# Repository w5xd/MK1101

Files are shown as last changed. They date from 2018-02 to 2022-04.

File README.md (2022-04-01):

# MK1101 through MK1104
Morse generation and single-operator-on-2-Radios controller<br/>
Much more information and complete instructions are on the <a href='http://github.com/w5xd/MK1101/wiki'>Wiki</a>.

The most current design is the MK-1104 with its 3D printed enclosure. An older design, from 2017, is the MK-1101 and MK-1102 which
fit into aluminum enclosures manufactured by Bud. All the devices are functionally identical and nearly so with the much older MK-1100
that was manufactured by HAL.

The TextFixture and the Arduino sketch are shared among all the designs.

<h2>MK-1103 and MK-1104. 3D printed enclosures</h2>
MK1104-schematic.sch is an <a href='http://expresspcb.com'>expresspcb.com</a> schematic for both the MK1103 and MK1104.<br/>
MK1103-main.rrb is an <a href='http://expresspcb.com'>expresspcb.com</a> printed circuit layout for the main board used by both MK1103 and MK1104<br/>
MK1104-aux.rrb is an <a href='http://expresspcb.com'>expresspcb.com</a> printed circuit layout for the aux board used by the MK-1104.<br/>
TestFixture.rrb is an <a href='http://expresspcb.com'>expresspcb.com</a> printed circuit layout for a test fixture that eases check out and diagnostics.<br/>
MK110x.ino is the arduino firmware for all the variants.<br/>

<h2>MK-1101 and MK-1102. Aluminum enclosures from Bud</h2>

MK1102-schematic.sch is an <a href='http://expresspcb.com'>expresspcb.com</a> schematic for both the MK1101 and MK1102.<br/>
MK1101-main.rrb is an <a href='http://expresspcb.com'>expresspcb.com</a> printed circuit layout for the main board used by both MK1101 and MK1102<br/>
MK1102-aux.rrb is an <a href='http://expresspcb.com'>expresspcb.com</a> printed circuit layout for the aux board used by the MK-1102.<br/>
TestFixture.rrb is an <a href='http://expresspcb.com'>expresspcb.com</a> printed circuit layout for a test fixture that eases check out and diagnostics.<br/>
MK110x.ino is the arduino firmware.<br/>
MK1101-drilling-template.odg is an OpenOffice document with the drilling template drawing.<br/>
MK1101-lettering.odg is an OpenOffice document with the silkscreening.<br/>
pdfs of the OpenOffice templates are also in the pdf folder of this source archive.

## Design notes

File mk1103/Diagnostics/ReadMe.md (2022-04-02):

 This is a Win32 program that controls the AC0 and AC1 outputs on the FT232H chip made by ftdichip.com 
and used in
the MK-1103 and MK-1104. Those keyers have a solid state relay circuit that routes the TXD and RXD lines
from the FT232H normally to the RS232 level converter and the back panel Rig connector.
If AC0 is held low with AC1 high, the relay latches such that the arduino's TXD/RXD are on the COM port such that
its diagnostics can be run from through the FT232H. The Arduino can also have its program uploaded
with the latch in that state.

The FT232H has EEPROM settings that determine its power up state for AC0 and AC1 (among other settings.)
The EEPROM can be programmed using the FT-PROG program from ftdi: 
<a href='https://ftdichip.com/utilities/#ft_prog'>https://ftdichip.com/utilities/#ft_prog</a>
The MK-1103 and MK-1104 are specified to be programmed with EEPROM setting Drive_0 for AC1 and Drive_1 for
AC0, which routes the serial UART to the RS232 back panel Rig connector.

There are alternatives. Programming the EEPROM for AC1 high and AC0 low puts the FT232H and solid state
relay in diagnostic mode at power up (and therefore disables the Rig connector.)

The power up reset circuit on pin 1 of U20A holds the pin low long
enough to override the EEPROM settings. That means you may use ft_prog to program the FT232H EEPROM for
 AC0 to Drive_1 and AC1 to Tristate which sets
the EEPROM to leave the latch unchanged. That makes this program useful. Invoking this program for that EEPROM
setup sets or clears the latch:
  Diagnostics COMn on    sets the latch for diagnostics
  Diagnostics COMn off   sets the latch for RS232 on the Rig connector.

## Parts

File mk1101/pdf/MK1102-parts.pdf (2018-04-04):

## Cart Tools

### Input

New Cart - create a new empty cart
Fast Add - bulk add multiple part numbers to your cart
Add Carts - add previous carts
Add BOM - add existing BOMs
Add Quote - add previous Quotes Resume Cart - resume a previous cart Upload to Cart - upload a file, csv, txt, xls, xlsx

Upload to Cart

### Options

Schedule Shipments - schedule your order for a future release
Update Stock Status - refresh the quantity available

### Output

Download - save a copy of your cart in spreadsheet format
Cart Share - create a new cart including only the quantity, part number, and customer reference

Cart Share

Shopping Cart: MK1101-with aux

Web ID | 176618232 Access ID | 69159 Salesorder Number Uncommitted

Checkout Pricing is valid for this Web ID until 5/4/2018 if you place your order online.
Quantities are not reserved until the order has been submitted. | Continue Shopping
Quantity | Part Number | Customer Reference

All prices are in USD.

Index | Quantity | Image | Part Number | Description | Customer Reference | Available Quantity | Backorder Quantity | Unit Price | Extended Price
| | | | | CAP TANT 1UF 35V 10% RADIAL | | 5 Immediate | 0 | 1.09000 | $5.45
| | | | | CONN HEADER 32POS SOCKET 2.54MM | | 4 Immediate | 0 | 1.63000 | $6.52
| | | | | CONN HEADER 40 POS 2.54 | | 4 Immediate | 0 | 1.44000 | $5.76
| | | | | CAP CER 0.047UF 50V X7R RADIAL | | 12 Immediate | 0 | 0.15900 | $1.91
| | | | | FT232H USB TO GPIO/SPI/I2C | | 1 Immediate | 0 | 14.95000 | $14.95
| | | | | CAP CER 1000PF 50V X7R RADIAL | | 12 Immediate | 0 | 0.13300 | $1.60
| | | | | AUDIO MAGNETIC INDICATOR 4-7V TH | | 1 Immediate | 0 | 1.51000 | $1.51
| | | | | IC DUAL RS232 ESD-PROT 16-DIP | | 1 Immediate | 0 | 1.61000 | $1.61
| | | | | TRANS NPN 40V 0.2A TO-92 | | 3 Immediate | 0 | 0.21000 | $0.63
| | | | | POT 100K OHM 1/20W PLASTIC LIN | | 1 Immediate | 0 | 1.29000 | $1.29
| | | | | CONN HEADER .100" DUAL STR 40POS | | 3 Immediate | 0 | 0.93000 | $2.79
| | | | | ATMEGA328 ARDUINO PRO MINI 5V | | 1 Immediate | 0 | 9.95000 | $9.95
| | | | | OPTOISO 5KV 4CH DARLINGTON 16DIP | | 1 Immediate | 0 | 3.47000 | $3.47
| | | | | CONN D-SUB RCPT 25POS STR IDC | | 2 Immediate | 0 | 2.33000 | $4.66
1 | 399-1429-ND
2 | 732-2860-ND
3 | 732-5334-ND
4 | BC1082CT-ND
5 | 1528-1449-ND
6 | BC1072CT-ND
7 | 668-1458-ND
8 | 296-26139-5-ND
9 | 2N3904FS-ND
10 | 987-1708-ND
11 | S2011EC-20-ND
12 | 1568-1055-ND
13 | PS2502-4A-ND
14 | HFM25H-ND
Online Ordering | Digi-Key | https://www.digikey.com/classic/Ordering/AddPart.aspx

15 | 450-2102-ND
| SWITCH TOGGLE SPDT 3A 120V | 1 Immediate | 0 | 2.99000 | $2.99
| CBL RIBN 25COND 0.050 GRAY 10' | 1 Immediate | 0 | 9.98000 | $9.98
| CONN HEADER 40 POS RA 2.54 | 1 Immediate | 0 | 1.44000 | $1.44
| CBL RIBN 8COND 0.050 GRAY 10' | 1 Immediate | 0 | 11.25000 | $11.25
| IC LINE RCVR RS485 QUAD 16-DIP | 1 Immediate | 0 | 6.66000 | $6.66
| BOX ALUM BLACK 2.72"L X 4.53"W | 1 Immediate | 0 | 24.90000 | $24.90
| CONN SOCKET IDC 8POS DL SR 30AU | 2 Immediate | 0 | 0.99000 | $1.98
| IC DVR RS485 LOW PWR QUAD 16-DIP | 1 Immediate | 0 | 7.28000 | $7.28
| CONN PWR JACK 2X5.5MM KINKED PIN | 1 Immediate | 0 | 0.60000 | $0.60
| IC 8-BIT SHIFT REGISTER 16-DIP | 2 Immediate | 0 | 0.53000 | $1.06
| CONN SOCKET IDC 26POS DUAL 30AU | 2 Immediate | 0 | 2.03000 | $4.06
| CONN SOCKET IDC 10POS DUAL 30AU | 1 Immediate | 0 | 1.19000 | $1.19
| CBL RIBN 10COND 0.050 GRAY 5' | 1 Immediate | 0 | 3.36000 | $3.36
| CONN D-SUB PLUG 9POS STR IDC | 1 Immediate | 0 | 1.82000 | $1.82
| RES 180 OHM 1/8W 5% CF AXIAL | 3 Immediate | 0 | 0.10000 | $0.30
| IC REG LINEAR 5V 1A TO220-3 | 1 Immediate | 0 | 0.90000 | $0.90
TPMSCT-ND | DIODE GEN PURP 75V 150MA DO35 | 2 Immediate | 0 | 0.11000 | $0.22
| RELAY GENERAL PURPOSE SPDT 1A 5V | 0 Immediate | 2 Lead Time | 1.99000 | $3.98
16 | AE25G-10-ND
17 | 732-5350-ND
18 | MD08R-10-ND
19 | LTC488CN#PBF- ND
20 | 377-2511-ND
21 | 609-3568-ND
22 | LTC486CN#PBF- ND
23 | CP-202A-ND
24 | 296-1600-5-ND
25 | 609-1742-ND
26 | 609-1739-ND
27 | AE10G-5-ND
28 | HMM09H-ND
29 | CF18JT180RCT- ND
30 | LM7805ACT-ND
31 | 1N4148-
32 | Z773-ND
33 | 497-5231-1-ND

DIODE GEN
PURP 600V
5A DO201AD

1
Immediate | 0 | 0.97000 | $0.97

Copyright © 1995-2018, Digi-Key Electronics. All Rights Reserved.
701 Brooks Avenue South,
Thief River Falls, MN 56701 USA
Continue Shopping | Checkout
Questions? Give us a call at 1-800-344-4539 or chat with us now on | .
34 | 1568-1103-ND
IC BRIDGE USB-UART 5V MODULE | 1 Immediate | 0 | 14.95000 | $14.95
CONN PWR PLUG 2.1X5.5MM SOLDER | 1 Immediate | 0 | 1.04000 | $1.04
RES 10K OHM 1/8W 5% CF AXIAL | 1 Immediate | 0 | 0.10000 | $0.10
RES 1K OHM 1/8W 5% CF AXIAL | 7 Immediate | 0 | 0.10000 | $0.70
CONN JACK STEREO 3.5MM R/A | 0 Immediate | 9 Lead Time | 2.30000 | $20.70
35 | CP3-1000-ND
36 | CF18JT10K0CT- ND
37 | CF18JT1K00CT- ND
38 | CP-3504-ND
Subtotal | $184.53
Shipping | Estimate
Sales Tax | unknown
Total | unknown

Are you shipping outside the United States?

Information: Please refer to our Terms and Conditions and Privacy Statement.

Live Chat

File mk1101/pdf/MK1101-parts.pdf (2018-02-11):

## Cart Tools

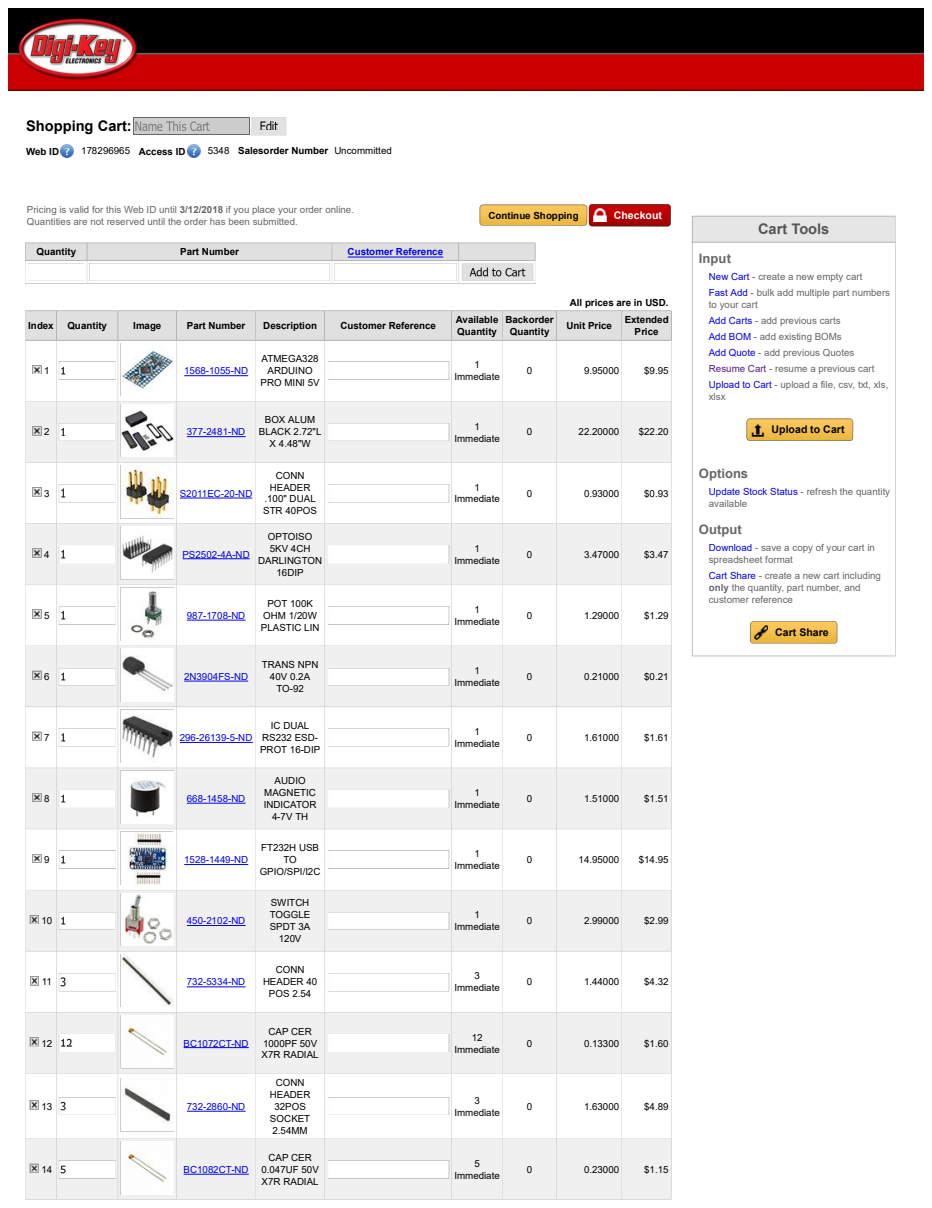
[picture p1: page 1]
Upload to Cart - upload a file, csv, txt, xls, xlsx; Upload to Cart; Shopping Cart: Web ID; 178296965 Access ID; 5348 Salesorder Number Uncommitted; Checkout Pricing is valid for this Web ID until 3/12/2018 if you place your order online.; Quantities are not reserved until the order has been submitted.; Continue Shopping; Quantity; Part Number; Customer Reference; All prices are in USD.

Input New Cart - create a new empty cart Fast Add - bulk add multiple part numbers

to your cart Add Carts - add previous carts Add BOM - add existing BOMs

Index | Quantity | Image | Part Number | Description | Customer Reference | Available Quantity | Backorder Quantity | Unit Price | Extended Price

Add Quote - add previous Quotes Resume Cart - resume a previous cart

ATMEGA328 ARDUINO PRO MINI 5V | | 1 Immediate | 0 | 9.95000 | $9.95

BOX ALUM BLACK 2.72"L X 4.48"W | | 1 Immediate | 0 | 22.20000 | $22.20

Options
Update Stock Status - refresh the quantity available Output Download - save a copy of your cart in

CONN HEADER .100" DUAL STR 40POS | | 1 Immediate | 0 | 0.93000 | $0.93

4 | | | PS2502-4A-ND | OPTOISO 5KV 4CH DARLINGTON 16DIP | | 1 Immediate | 0 | 3.47000 | $3.47

spreadsheet format Cart Share - create a new cart including

only the quantity, part number, and
customer reference Cart Share

POT 100K OHM 1/20W PLASTIC LIN | | 1 Immediate | 0 | 1.29000 | $1.29

TRANS NPN 40V 0.2A TO-92 | | 1 Immediate | 0 | 0.21000 | $0.21

IC DUAL RS232 ESD- PROT 16-DIP | | 1 Immediate | 0 | 1.61000 | $1.61

AUDIO MAGNETIC INDICATOR 4-7V TH | | 1 Immediate | 0 | 1.51000 | $1.51

FT232H USB TO GPIO/SPI/I2C | | 1 Immediate | 0 | 14.95000 | $14.95

SWITCH TOGGLE SPDT 3A 120V | | 1 Immediate | 0 | 2.99000 | $2.99

CONN HEADER 40 POS 2.54 | | 3 Immediate | 0 | 1.44000 | $4.32

CAP CER 1000PF 50V X7R RADIAL | | 12 Immediate | 0 | 0.13300 | $1.60

CONN HEADER 32POS SOCKET 2.54MM | | 3 Immediate | 0 | 1.63000 | $4.89

CAP CER 0.047UF 50V X7R RADIAL | | 5 Immediate | 0 | 0.23000 | $1.15

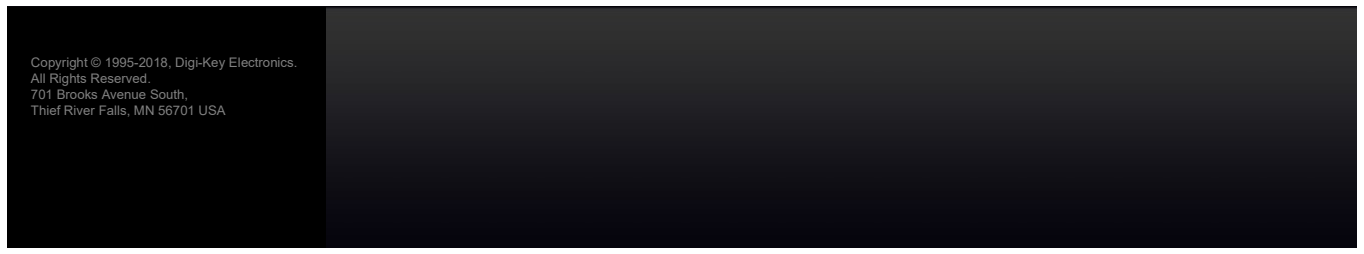
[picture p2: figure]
All Rights Reserved. 701 Brooks Avenue South, Thief River Falls, MN 56701 USA

Copyright © 1995-2018, Digi-Key Electronics.

Continue Shopping | Checkout
Questions? Give us a call at 1-800-344-4539 or chat with us now on | .

15 399-1429-ND

CAP TANT 1UF 35V 10% RADIAL | 4 Immediate | 0 | 1.09000 | $4.36
CONN JACK STEREO 3.5MM R/A | 0 Immediate | 6 Lead Time | 2.30000 | $13.80
CONN D-SUB PLUG 9POS STR IDC | 1 Immediate | 0 | 1.84000 | $1.84
CBL RIBN 10COND 5' 0.050 GRAY | 1 Immediate | 0 | 3.36000 | $3.36
IC BRIDGE USB-UART 5V MODULE | 1 Immediate | 0 | 14.95000 | $14.95
CONN SOCKET IDC 10POS DUAL 30AU | 1 Immediate | 0 | 1.19000 | $1.19
CONN HEADER 40 POS RA 2.54 | 1 Immediate | 0 | 1.44000 | $1.44
RES 10K OHM 1/8W 5% CF AXIAL | 1 Immediate | 0 | 0.10000 | $0.10
RES 1K OHM 1/8W 5% CF AXIAL | 5 Immediate | 0 | 0.10000 | $0.50

### 16 CP-3504-ND

### 17 HMM09H-ND

### 18 AE10G-5-ND

19 1568-1103-ND

20 609-1739-ND

21 732-5350-ND

### 22 CF18JT10K0CT- ND

### 23 CF18JT1K00CT- ND

Subtotal | | $112.61
Shipping | Estimate Sales Tax | unknown
Total | unknown Are you shipping outside the United States?

Information: Please refer to our Terms and Conditions and Privacy Statement. Live Chat

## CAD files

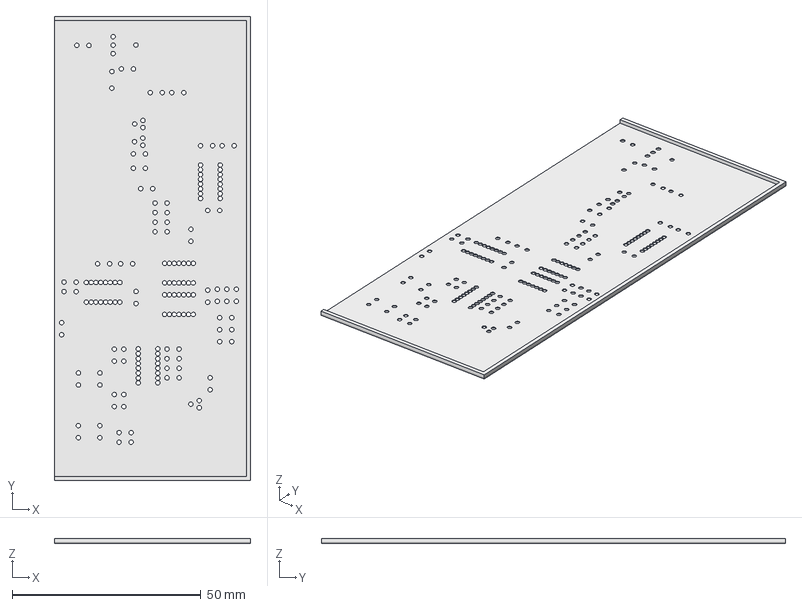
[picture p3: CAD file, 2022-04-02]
mk1103/pcb step/mk1103-main-solder-paste.step
52.0 x 123.0 x 1.20 mm

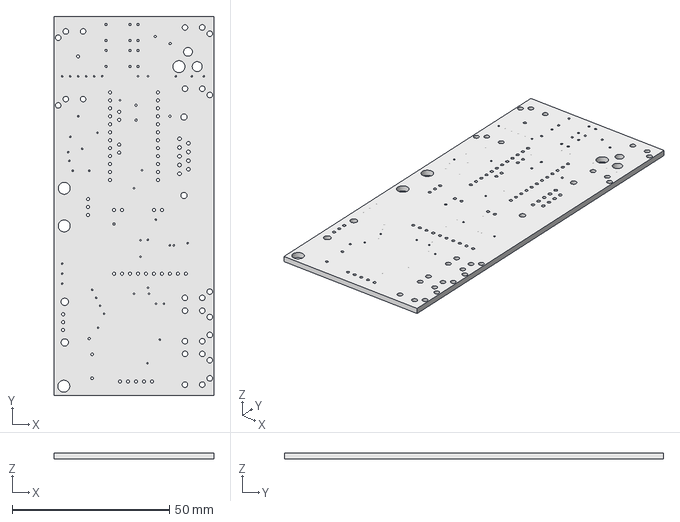
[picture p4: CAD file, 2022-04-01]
mk1103/pcb step/pcb-main.step
50.8 x 120.7 x 1.78 mm

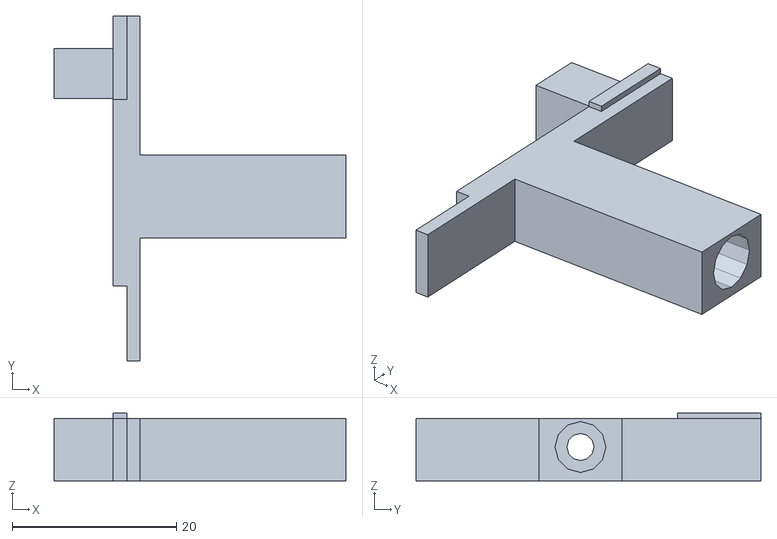
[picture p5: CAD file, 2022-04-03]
mk1103/STL/pcb-main-brace.stl
35.6 x 42.1 x 8.26

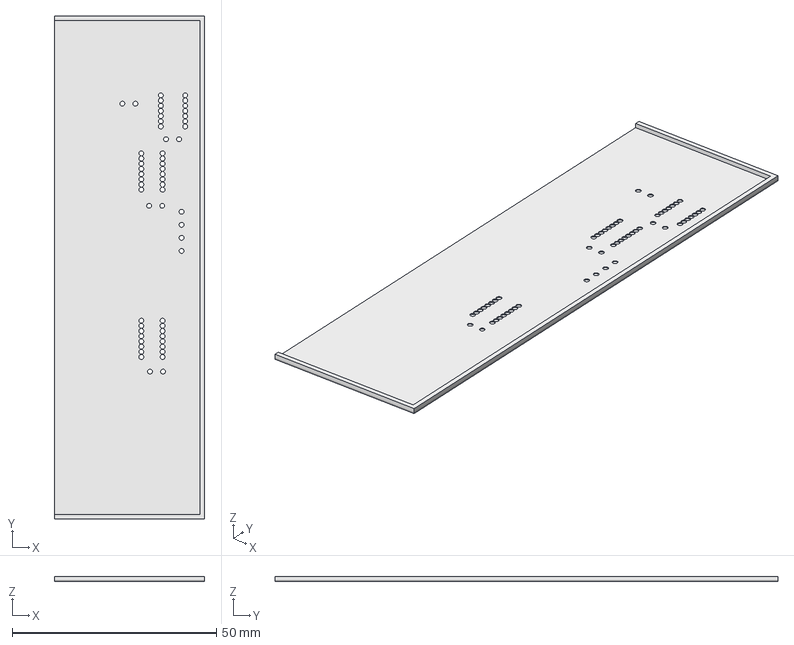
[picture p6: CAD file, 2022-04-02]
mk1103/pcb step/mk1104-solder-paste.step
36.8 x 123.0 x 1.20 mm

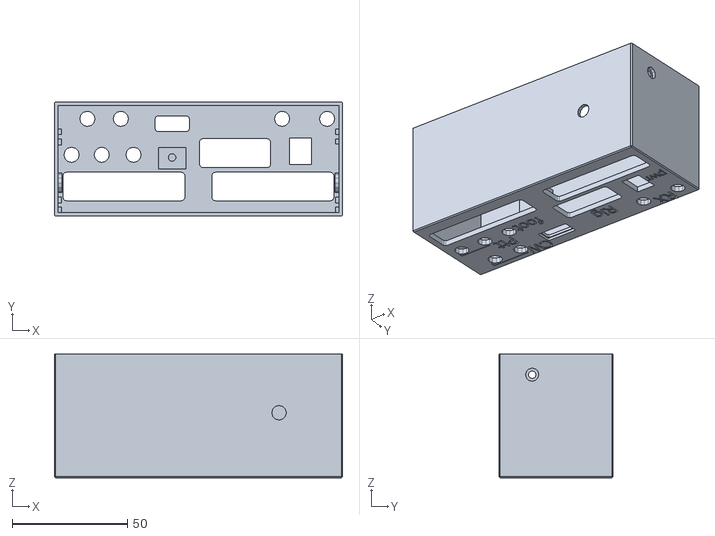
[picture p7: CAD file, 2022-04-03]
mk1103/STL/enclosure-1104-back.stl
124.8 x 49.6 x 53.6

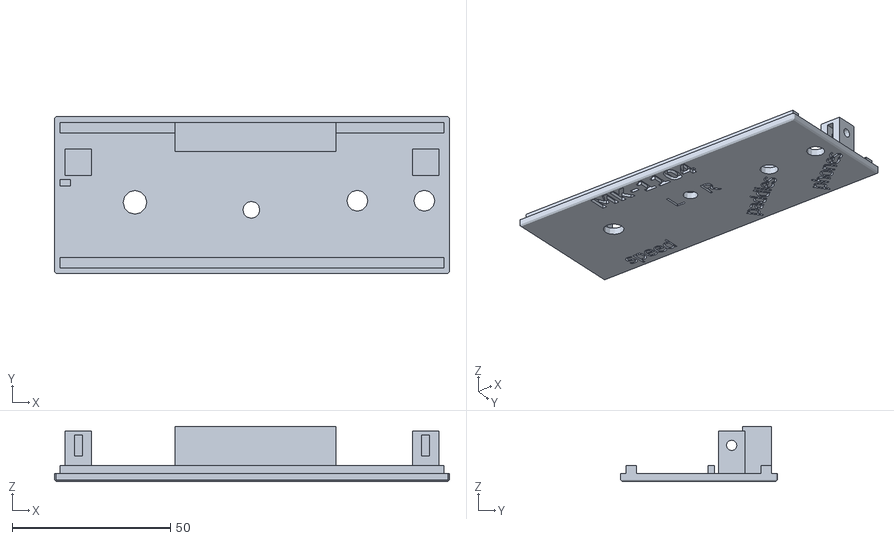
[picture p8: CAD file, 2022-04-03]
mk1103/STL/enclosure-1104-front.stl
124.8 x 49.6 x 17.4

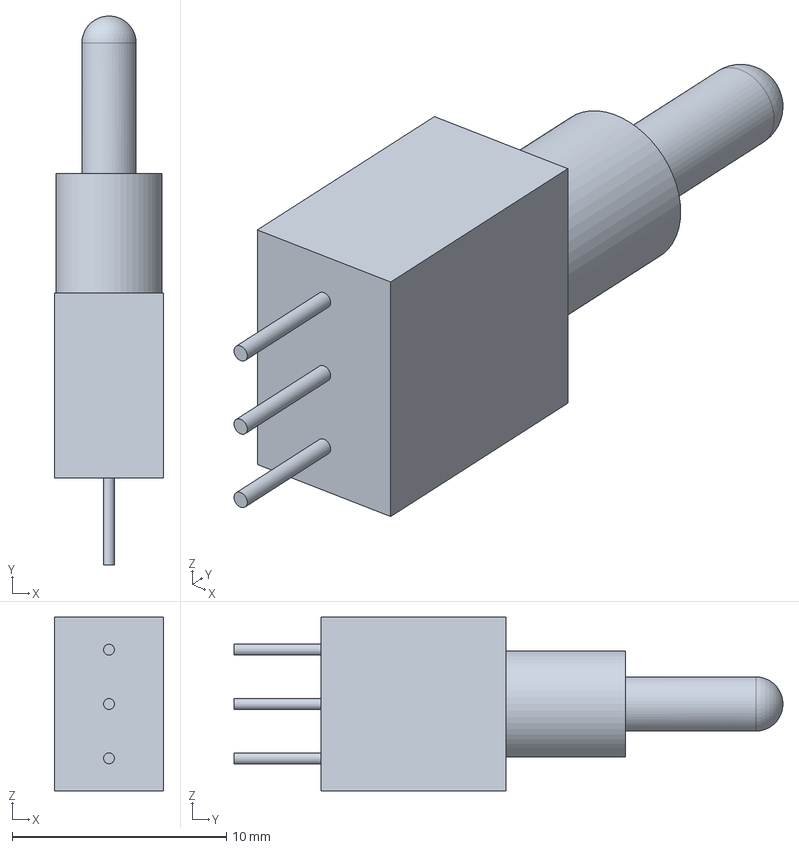
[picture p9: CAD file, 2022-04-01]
mk1103/pcb step/LR switch.stp
5.08 x 25.7 x 8.13 mm

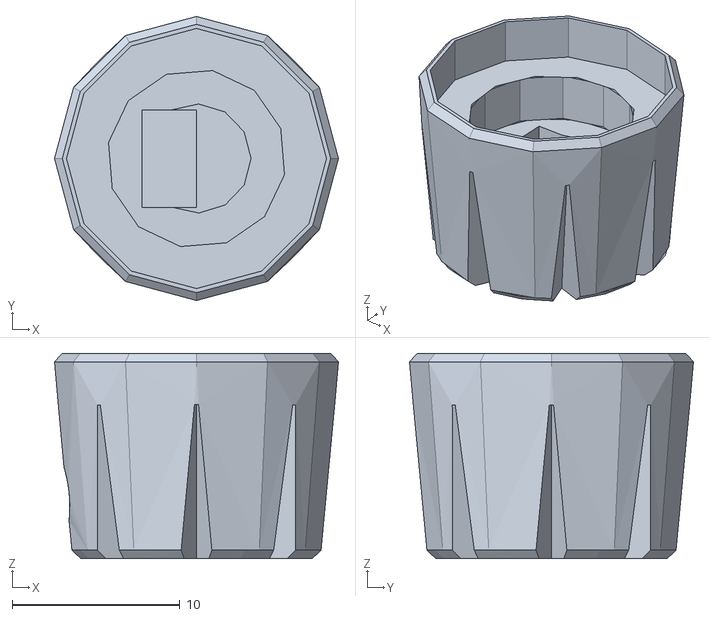
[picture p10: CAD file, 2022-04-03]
mk1103/STL/speed knob.stl
16.9 x 16.9 x 12.2

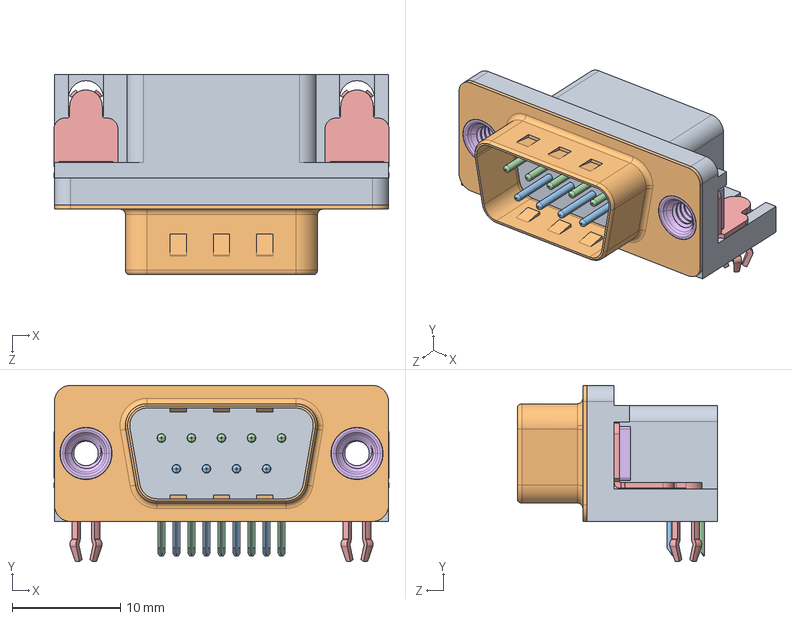
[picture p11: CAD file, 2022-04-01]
mk1103/pcb step/621-009-260-042 - EDAC D-Sub Connector.STEP
30.9 x 16.3 x 18.4 mm
621 Housing_9 Socket
621 Shell_9 Socket
621 Contact Bottom x 4
621 Contact Top x 5
621 4 Prong Board Lock x 2
621 4-40 Threaded Rivet x 2

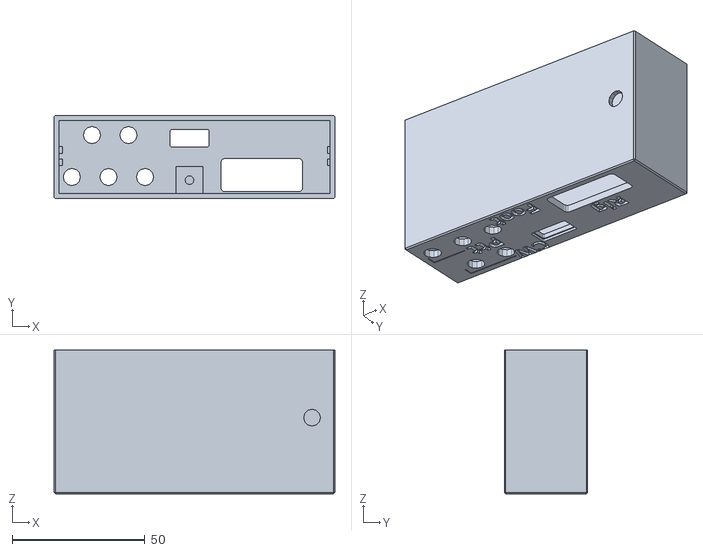
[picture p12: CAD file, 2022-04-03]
mk1103/STL/enclosure-1103-back.stl
105.9 x 31.4 x 54.1

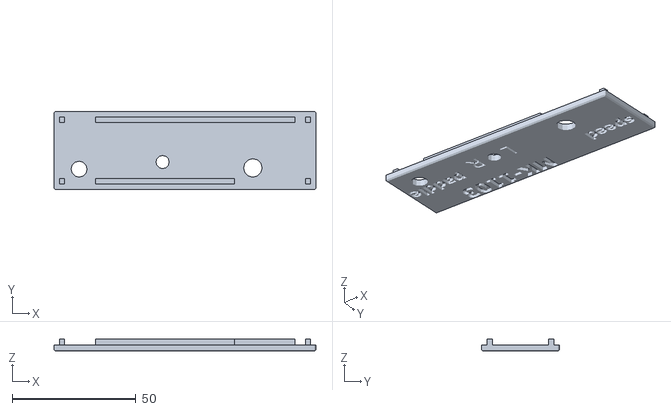
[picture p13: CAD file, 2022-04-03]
mk1103/STL/enclosure-1103-front.stl
105.9 x 31.4 x 5.01

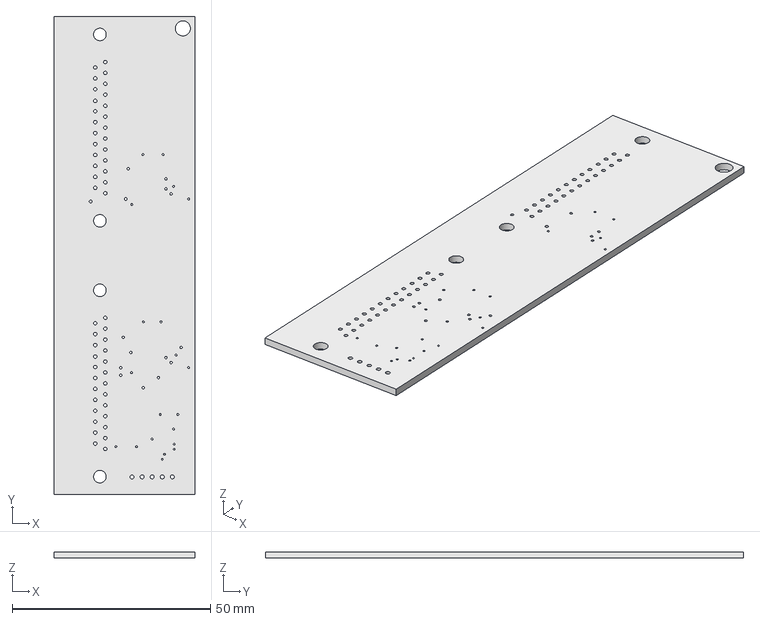
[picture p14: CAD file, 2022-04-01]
mk1103/pcb step/pcb-aux.step
35.6 x 120.7 x 1.59 mm

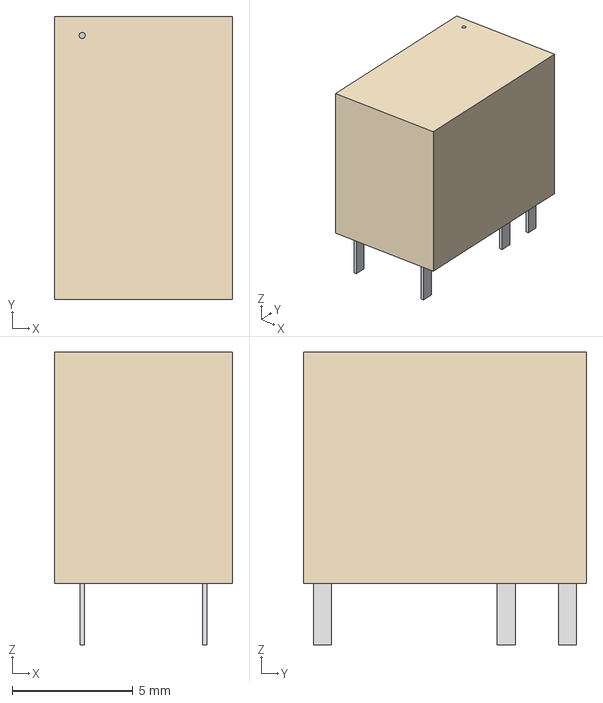
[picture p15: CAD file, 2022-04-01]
mk1103/pcb step/RELAY_HY1_PAN.step
7.39 x 11.7 x 12.1 mm

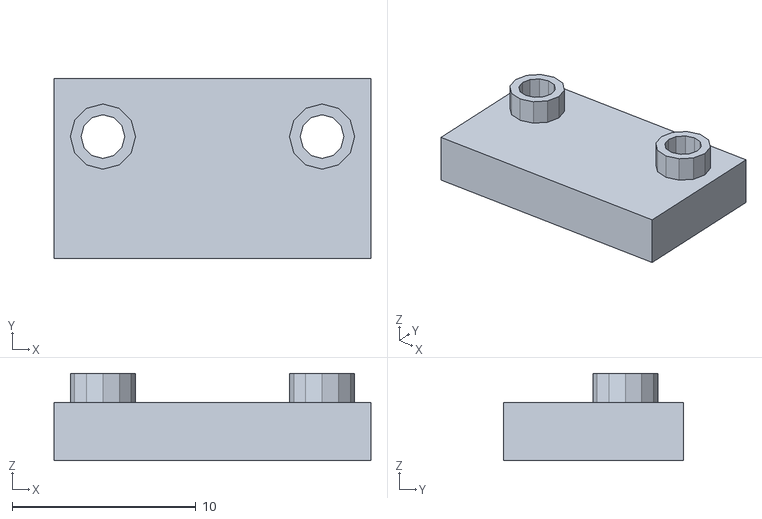
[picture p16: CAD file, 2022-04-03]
mk1103/STL/switch spacer.stl
17.3 x 9.83 x 4.76

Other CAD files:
mk1103/pcb step/Relay SPDT.stp
mk1103/pcb step/PDB25S564GTLF.stp
mk1103/pcb step/switch spacer.stp
mk1103/pcb step/speed pot.stp
mk1103/pcb step/buzzer.stp

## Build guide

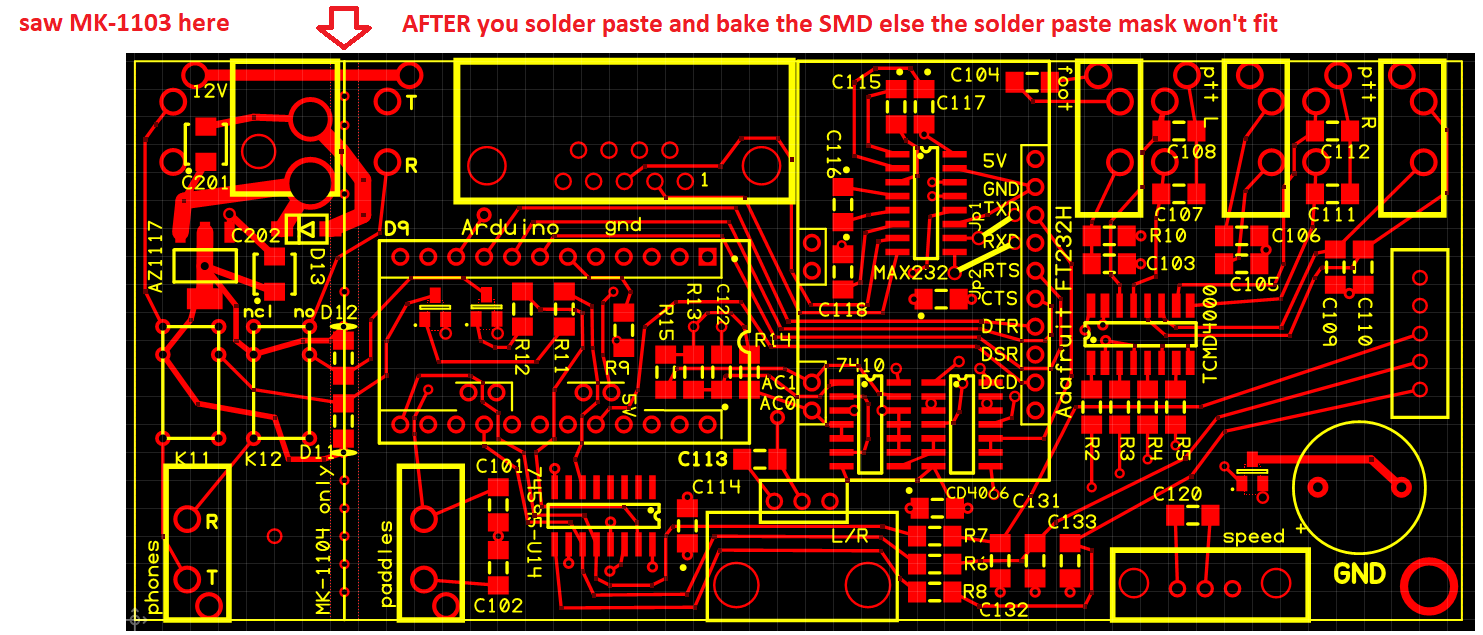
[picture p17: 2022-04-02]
mk1103/mk1103-board-cutting-instructions.png

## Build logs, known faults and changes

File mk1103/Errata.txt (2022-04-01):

Errata

1. The solder mask for the main board does NOT fit after the PCB is cut for the MK-1103 configuration. Therefore: do NOT cut the PCB
until AFTER the surface mount components are baked on.

2. The only bottom-side components (besides the D13 issue above) are: 
    FT232H breakout
    Ptt out connectors
    RX audio in connectors (and these are only present in the MK-1104 configuration)

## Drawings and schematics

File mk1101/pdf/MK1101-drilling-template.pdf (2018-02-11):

# Back

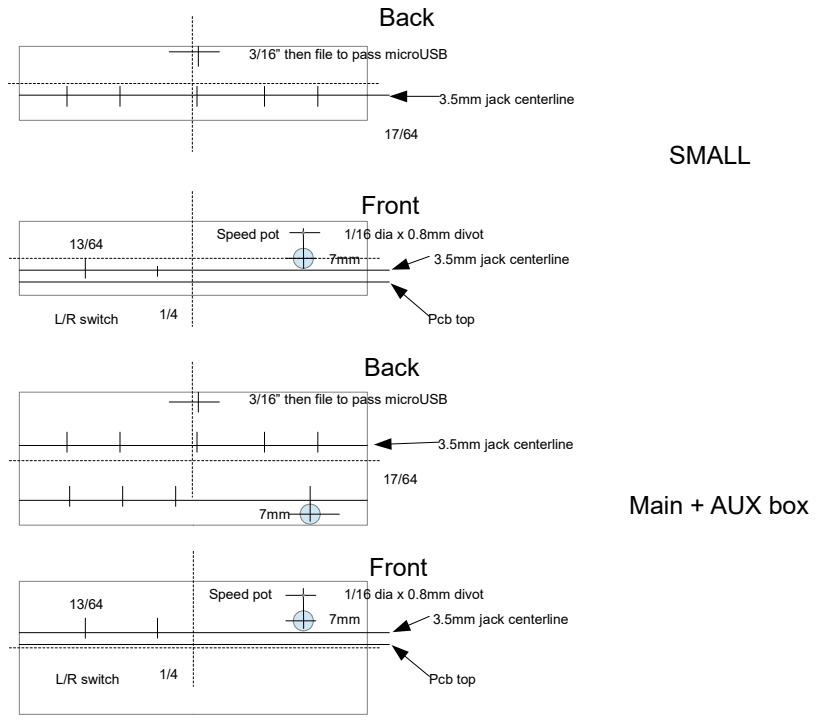
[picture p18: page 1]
3.5mm jack centerline; Pcb top; Front; Speed pot; L/R switch; 1/16 dia x 0.8mm divot 13/64; Back; SMALL; Main + AUX box

3/16” then file to pass microUSB

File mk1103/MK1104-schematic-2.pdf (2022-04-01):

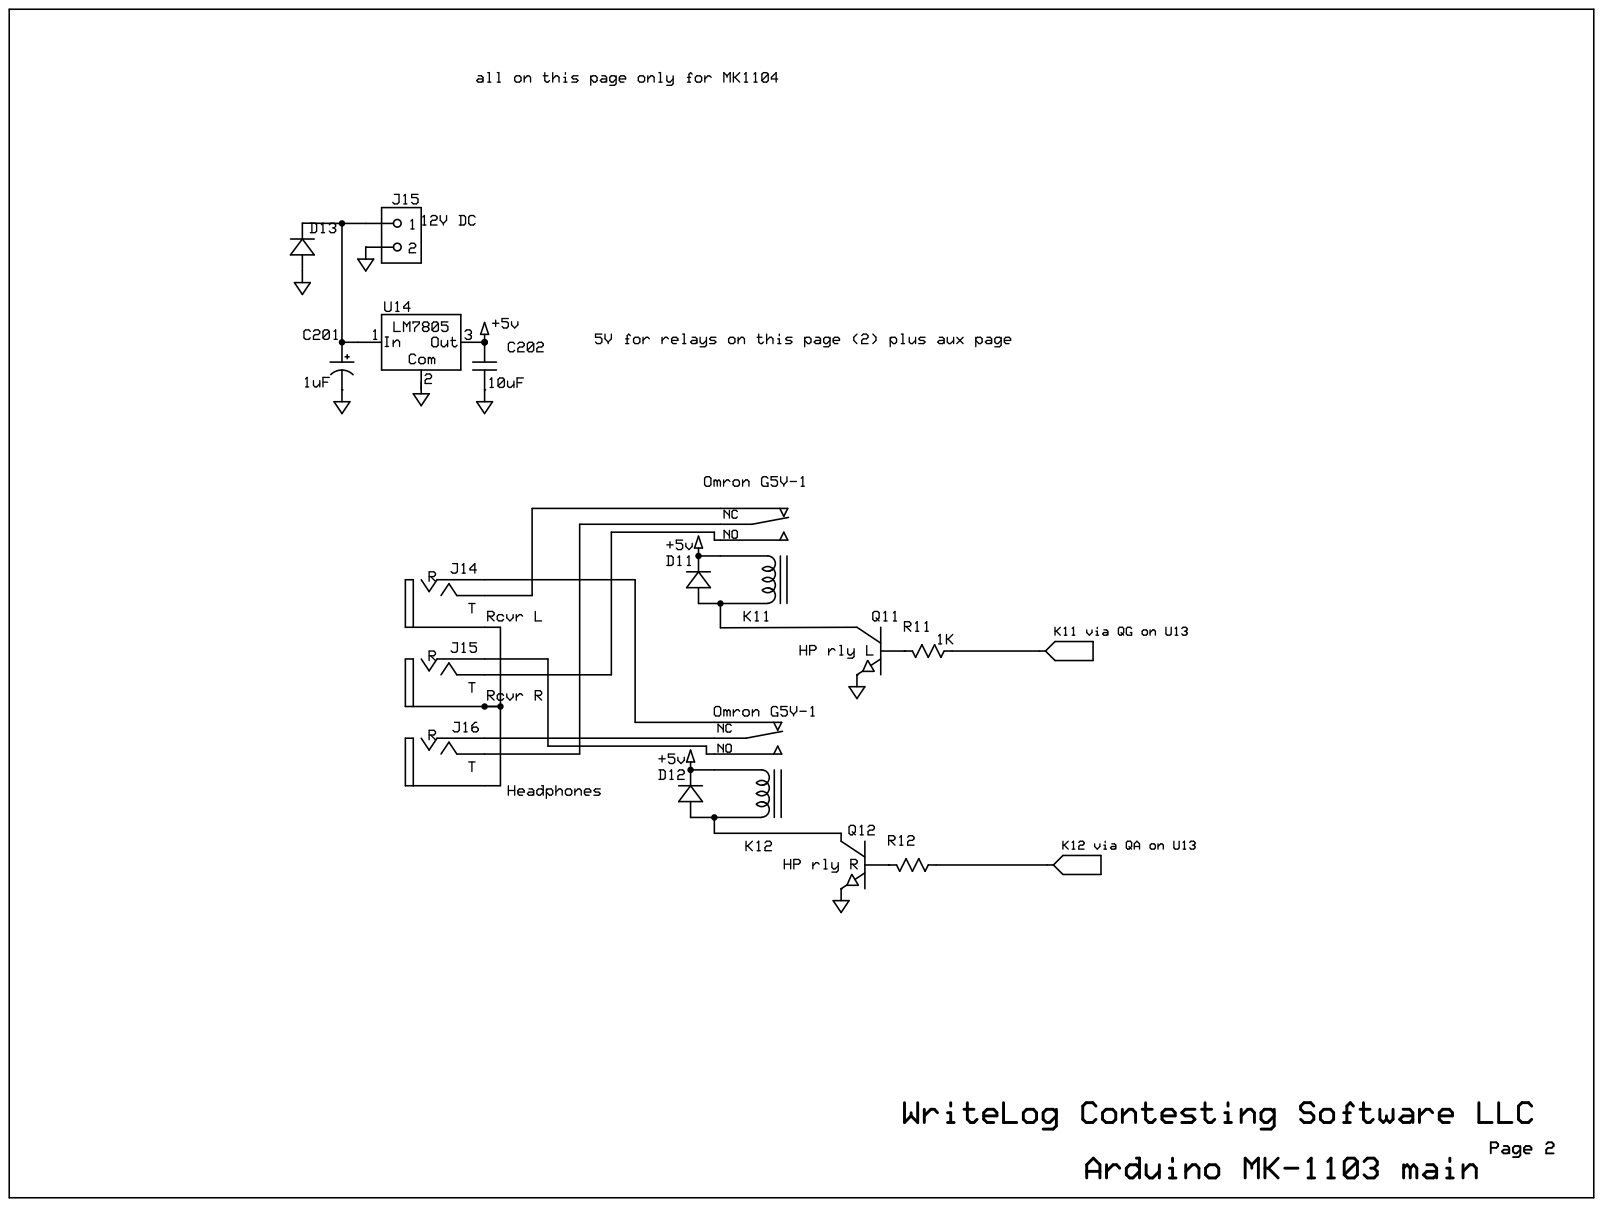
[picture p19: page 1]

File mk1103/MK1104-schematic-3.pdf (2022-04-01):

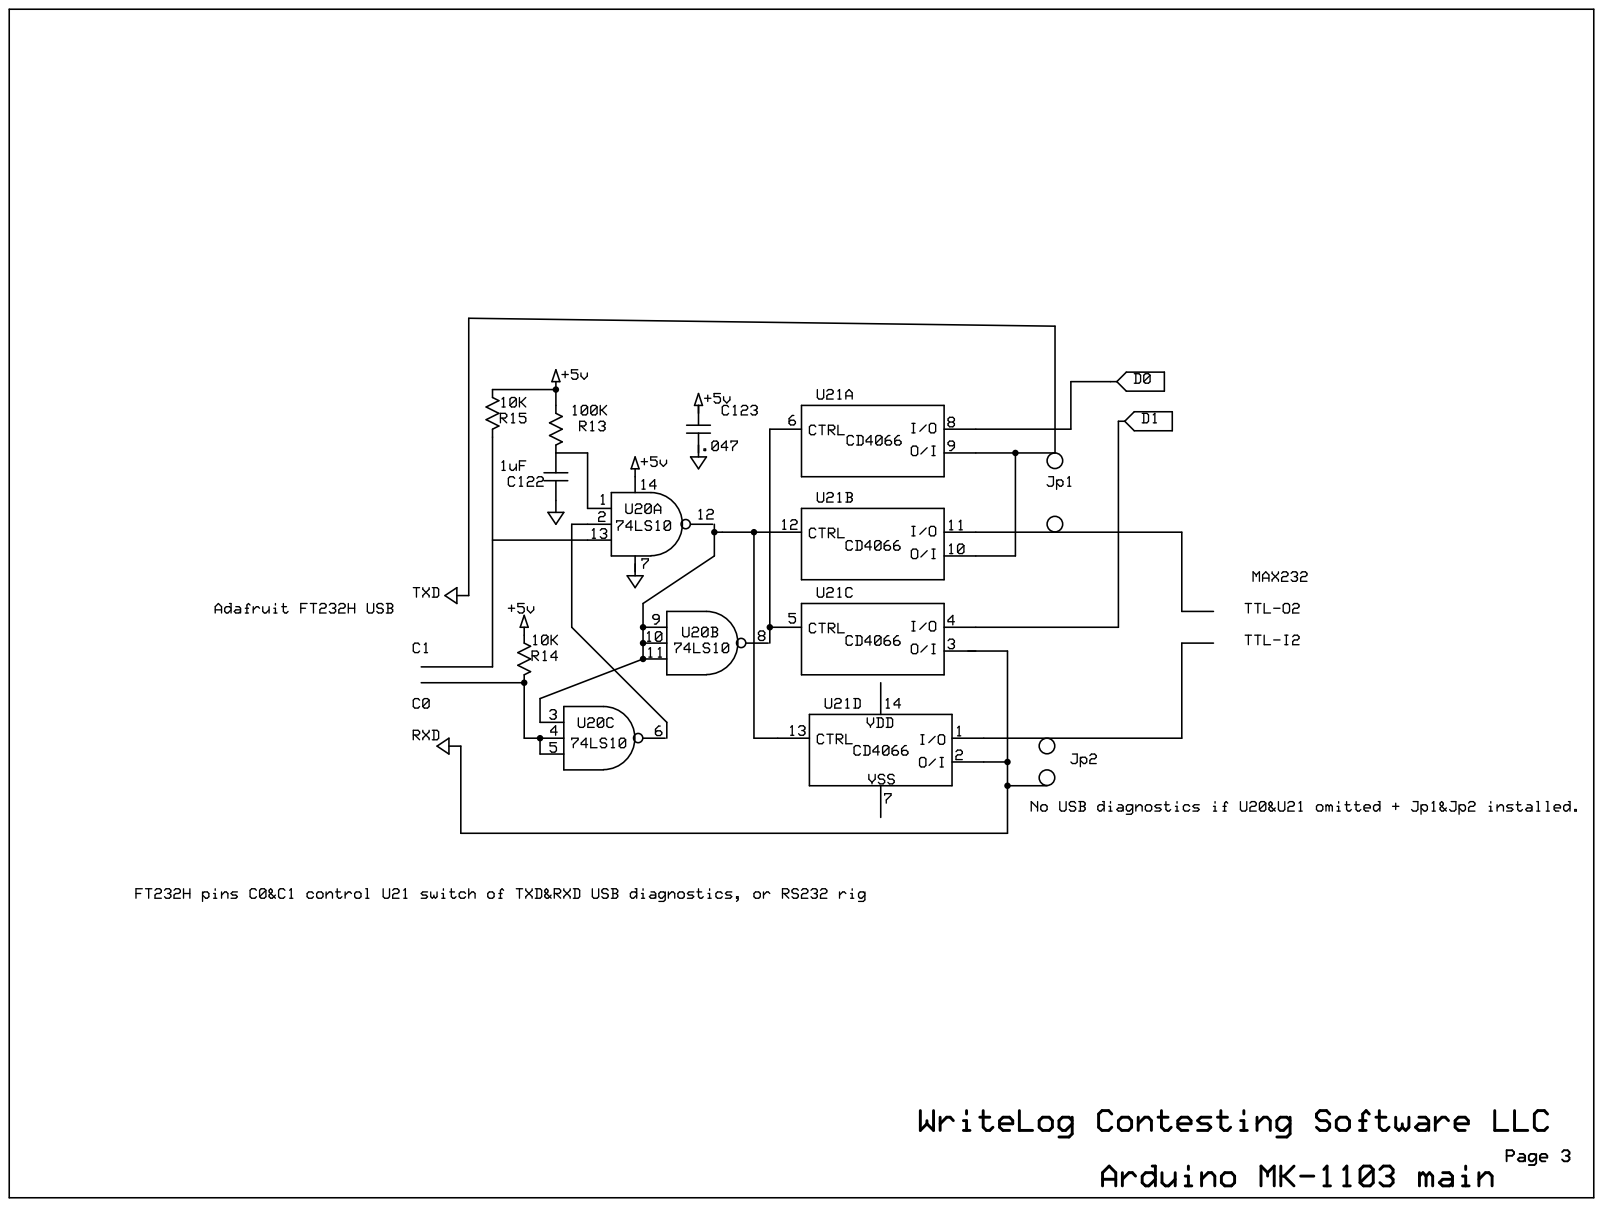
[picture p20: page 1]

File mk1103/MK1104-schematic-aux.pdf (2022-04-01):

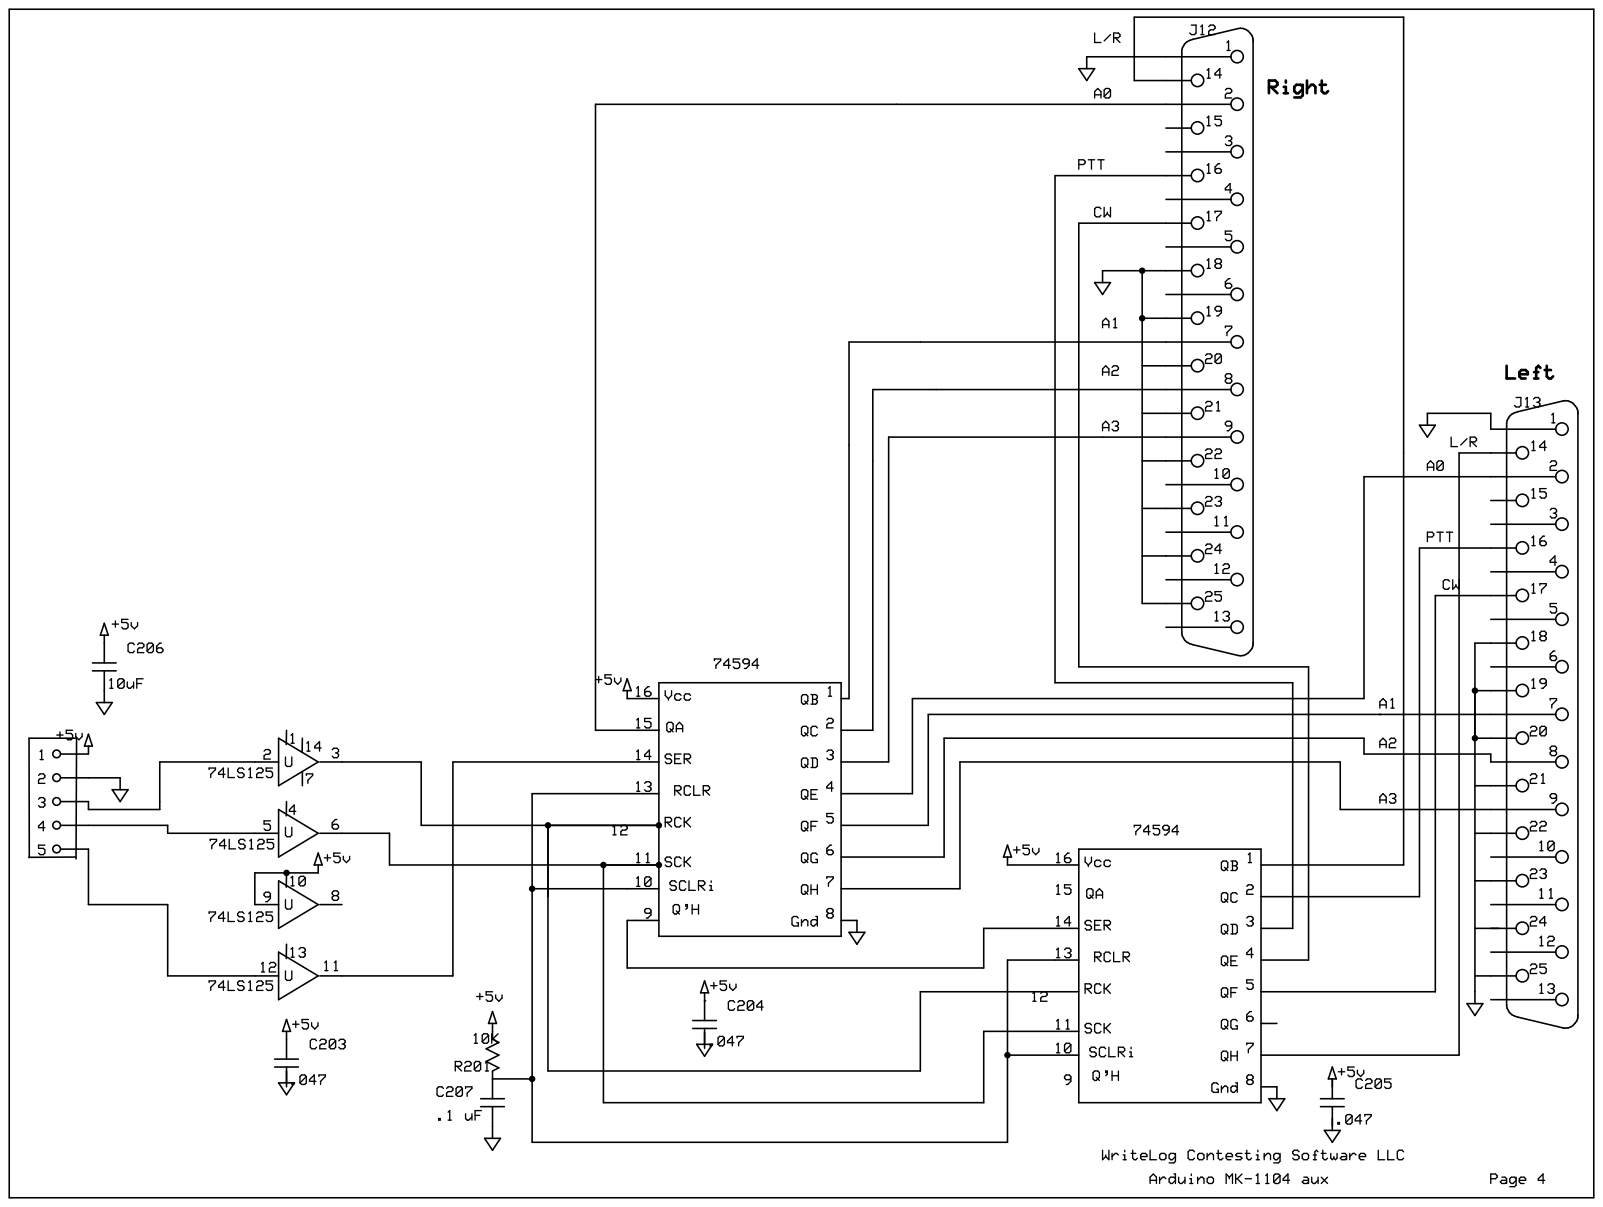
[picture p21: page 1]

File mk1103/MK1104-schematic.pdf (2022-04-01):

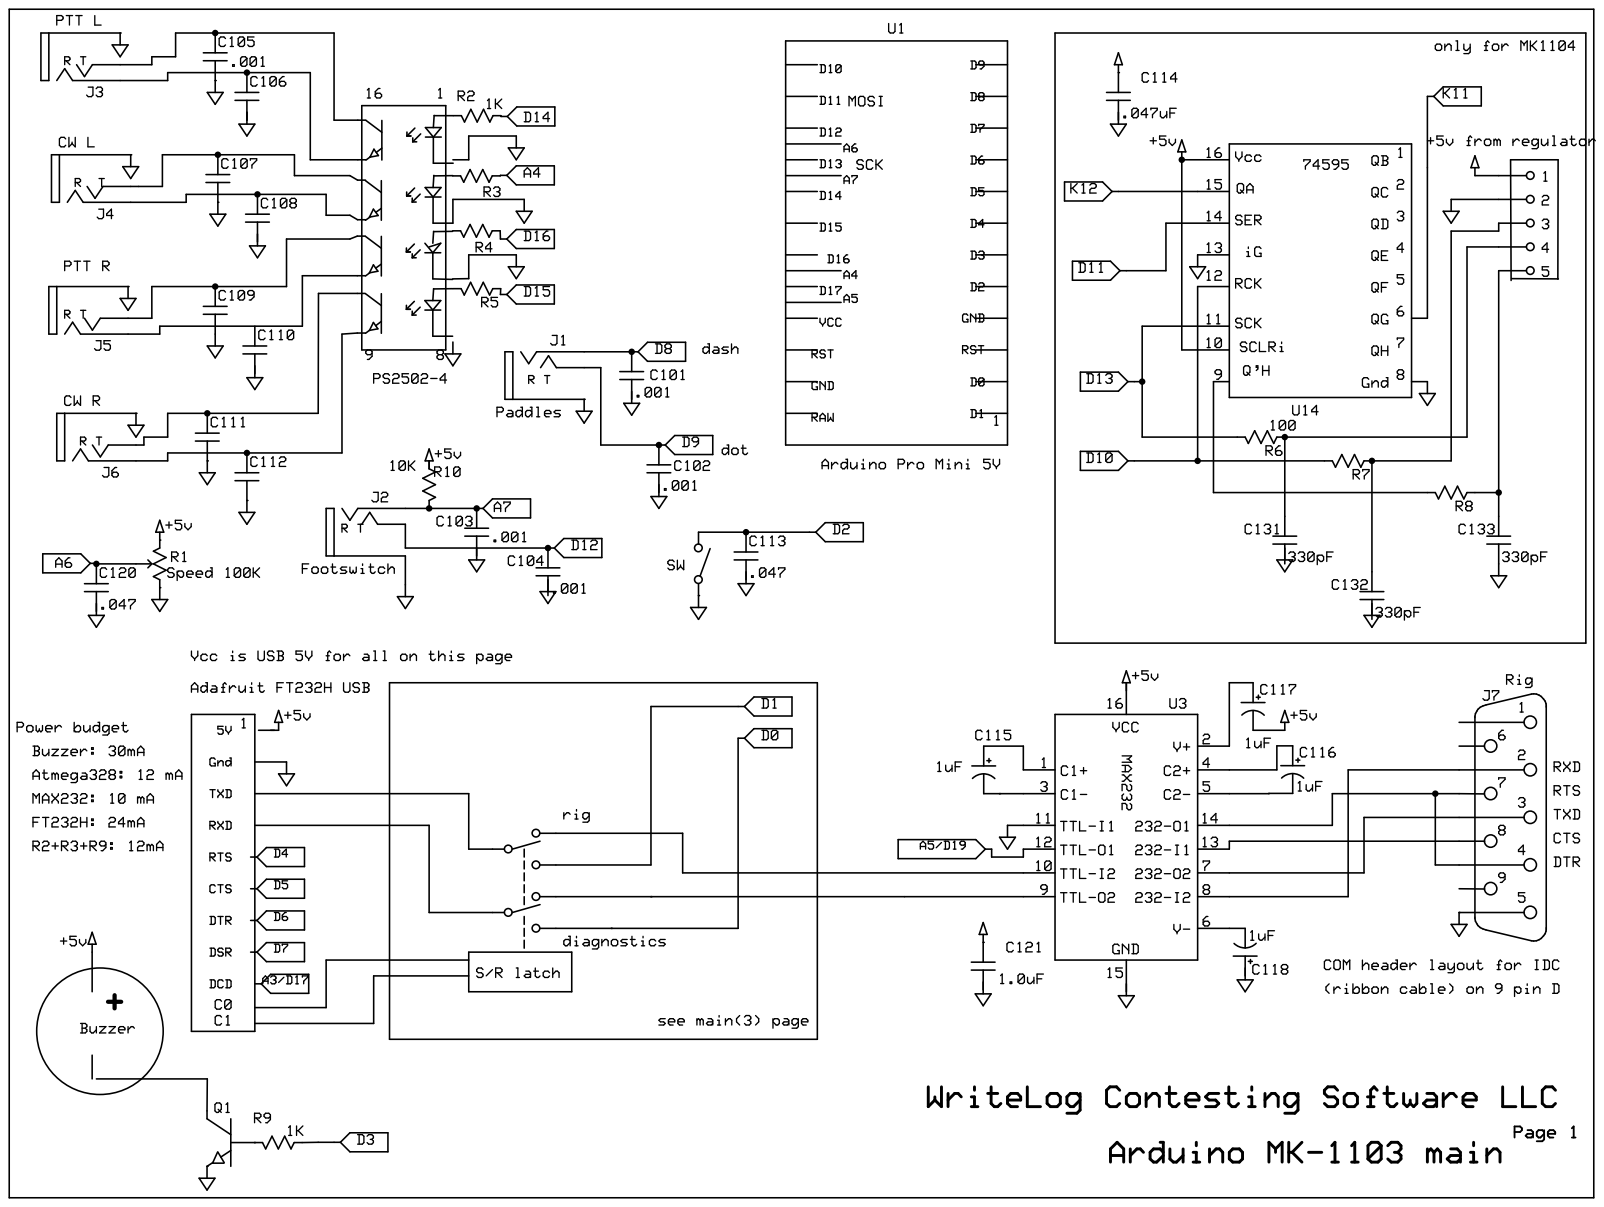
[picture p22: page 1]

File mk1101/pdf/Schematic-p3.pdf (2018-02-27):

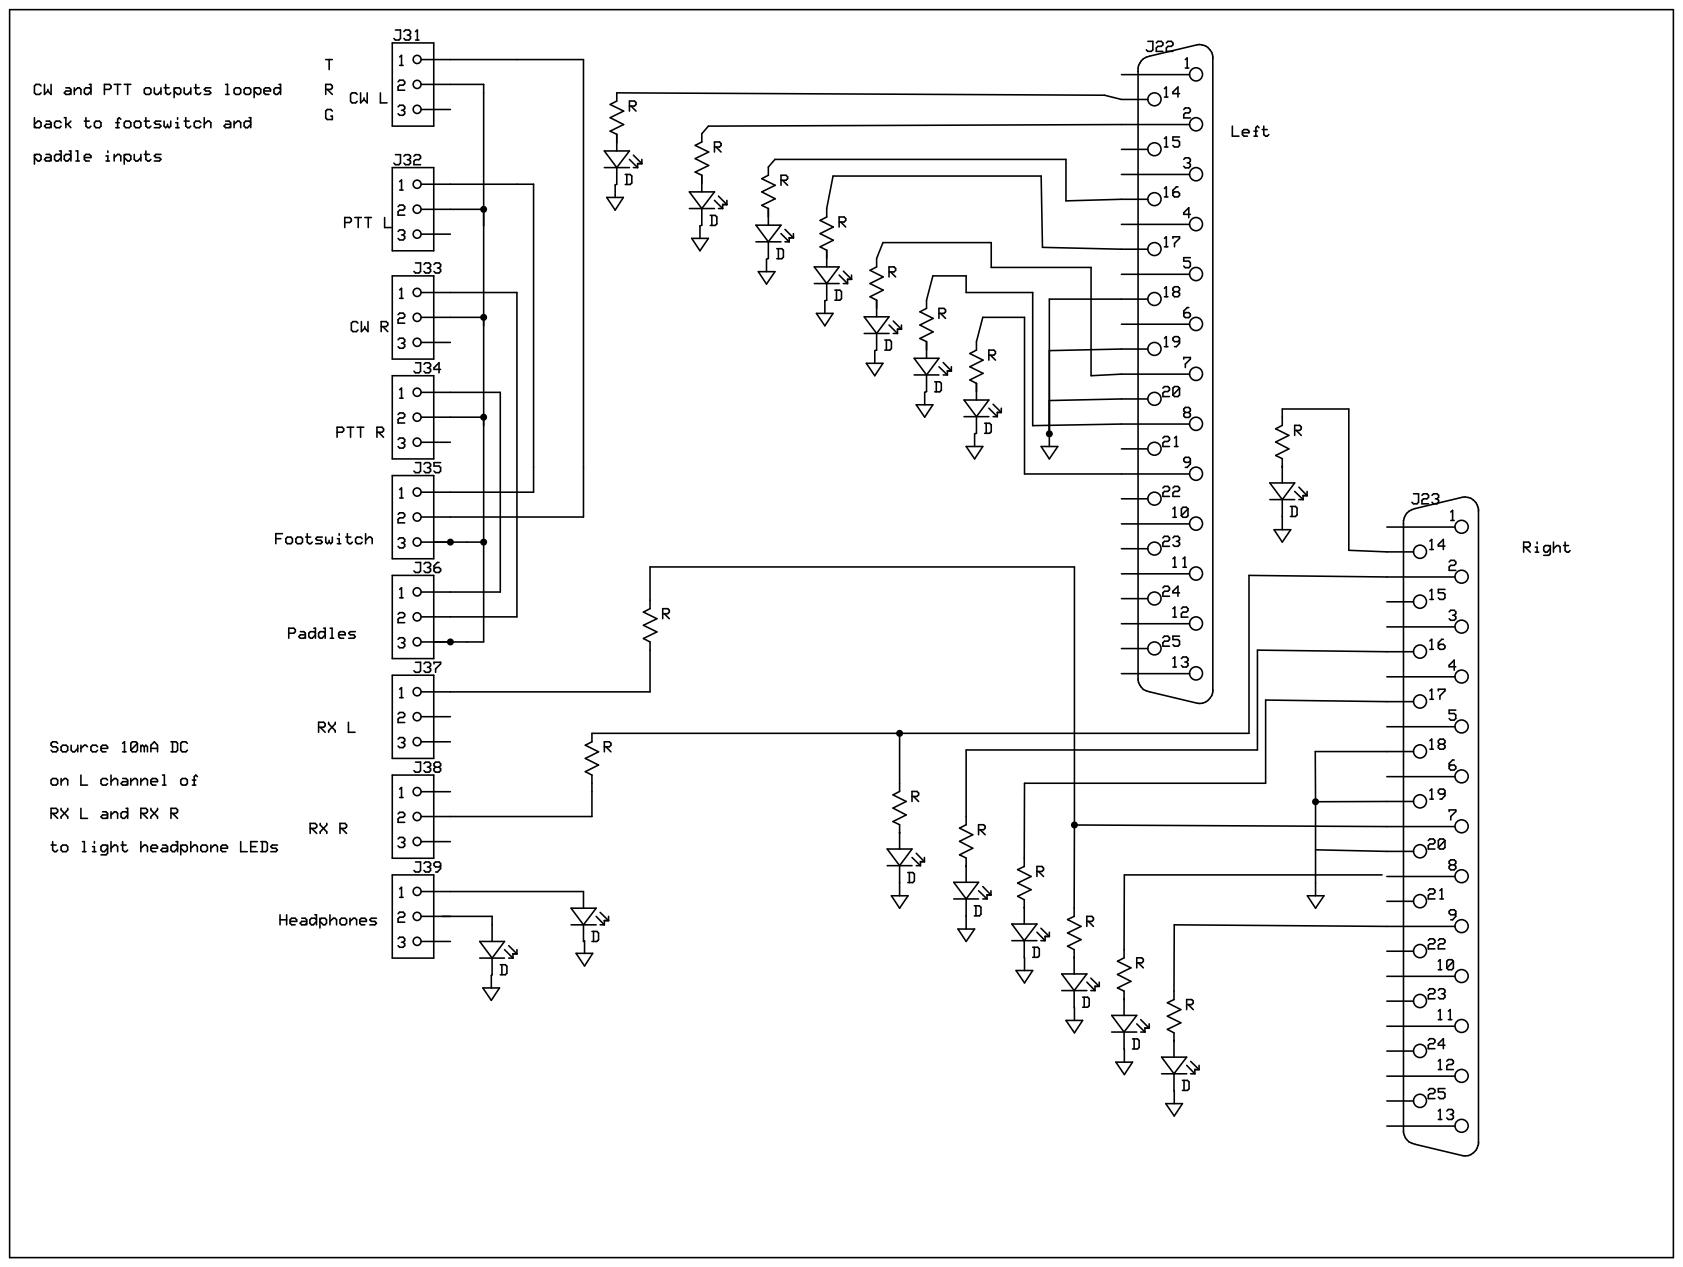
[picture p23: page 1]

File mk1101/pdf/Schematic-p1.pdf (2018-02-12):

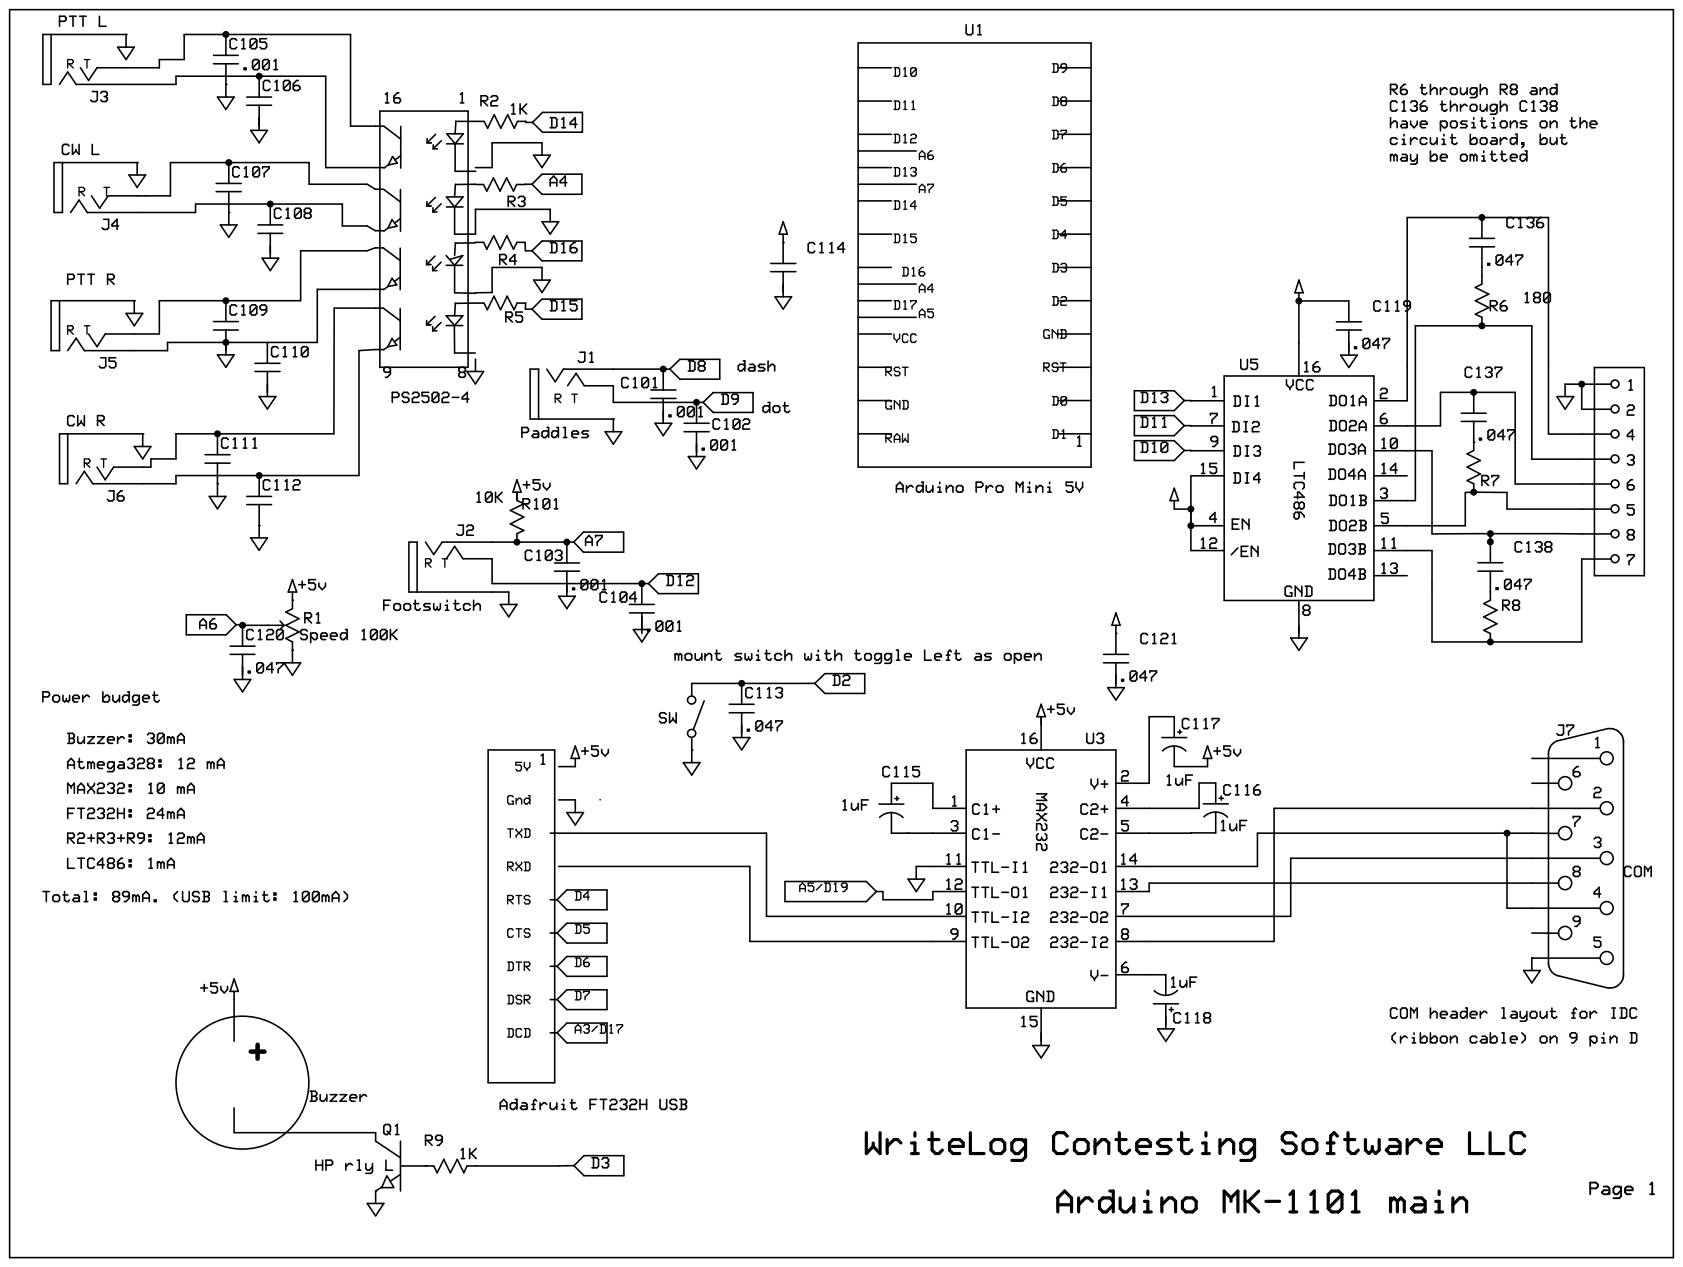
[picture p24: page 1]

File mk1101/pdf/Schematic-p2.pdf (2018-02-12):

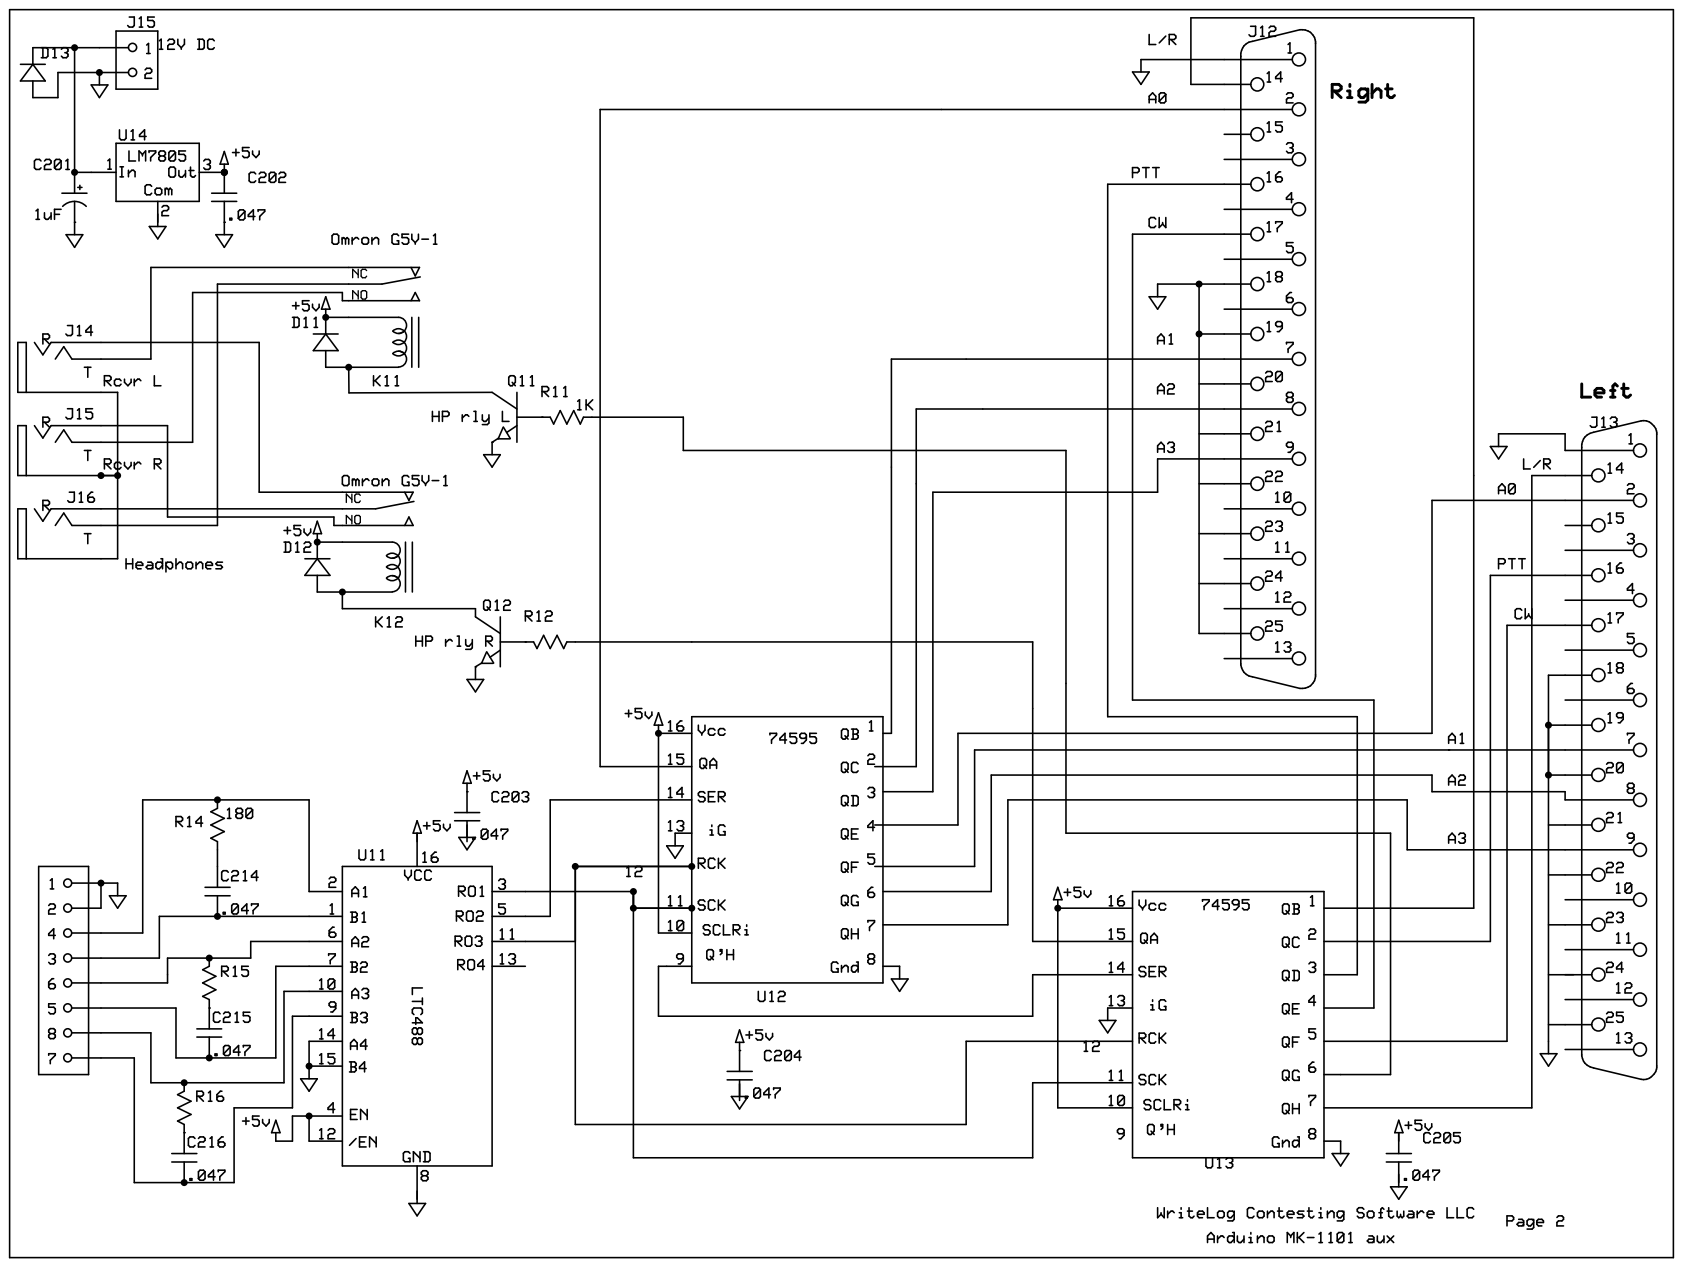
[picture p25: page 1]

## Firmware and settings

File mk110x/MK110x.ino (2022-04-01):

/* Copyright (C) 2018 by Wayne E. Wright, W5XD
 *  Round Rock, Texas
 *  
 * MK-1101 / MK-1102 / MK-1103 multi-keyer SO2R controller.
 * 
 * This sketch is an arduino implementation of the MK-1100 keyer originally
 * implemented on a Motorola 68HC705P microprocessor.
 * It is as close as I could think of to a literal port. The timer
 * is set to interrupt at 512usec intervals to match that used
 * in the MK-1100. This firmware works on the MK-1101, MK-1102, MK-1103
 * variants.
 * 
 * For programming novices that might be reading this:
 * This sketch is NOT a good example of much of anything other than
 * a port of 68HC705 assembly language to C++. The comments
 * have snippets of the original MK-1100 assembly language to
 * provide reference so that this port can behave identically to
 * the original. The names of variables and functions are those
 * used in the original firmware. Those kinds of things don't 
 * belong in C++ anymore, but they were useful for this particular
 * project.
 */
 
#include <Arduino.h>
#include <SPI.h>
#include <EEPROM.h>

#define MK1101_BUILD_DEFINITION 1
#define MK1102_BUILD_DEFINITION 1 // MK1101/MK1102 have identical code
#define MK1103_BUILD_DEFINITION 3 // different because the serial out on SPI has one more byte
#define MK1104_BUILD_DEFINITION MK1103_BUILD_DEFINITION // these two run identical firmware

#define MK110X_BUILD MK1103_BUILD_DEFINITION

#if (MK110X_BUILD == MK1101_BUILD_DEFINITION)
#define SPI_MK110x_HZ  10000000L // The line driver chips are rated to 10MHz
#else
#define SPI_MK110x_HZ   1000000L // The low pass on the MK1103 is about 4MHz
#endif

namespace {
/* The Ardunio Pro Mini has 20 I/O pins. ALL are allocated.
** This code will require work to run on other Arduino boards.
** Of course the 20 I/O pins defined here would have to be
** worked out. Also the 512usec timer interrupt code below
** is only operable on certain Atmega processors. */

// connections from Adafruit breakout to Arduino
    const int RTS_PIN = 4;
    const int CTS_PIN = 5;
    const int DTR_PIN = 6;
    const int DSR_PIN = 7;
    const int DCD_PIN = A3;

    //SPI to talk to aux BOARD
    const int SPI_SCK = 13;
    const int SPI_MOSI = 11;
// The MK-1102/1103 aux board is on SPI on select pin 10
    const int AUX_SELECT_PIN = 10;
    const int FOOTRING_PIN = A7;

    const int CWL_PIN = A4;
    const int CWR_PIN = 15;
    const int PTTL_PIN = 14;
    const int PTTR_PIN = 16;
    const int CW_SIDETONE_PIN = 3;

    const int CWDOT_PIN = 9;
    const int CWDASH_PIN = 8;
    const int FOOTTIP_PIN = 12; // MISO we're reading footswitch
    const int RIGCTS_PIN = A5;
    const int LRSWITCH_PIN = 2;
    const int SPEEDPOT_PIN = A6;

    // In order to run on hardware with no pot attached to SPEEDPOT_PIN...
    const int KNOB_EPROM_IDX = 0;
    const int KNOB_REVERSE_IDX = 1;
    const int PTT_DELAY_IDX=2;
    const int LR_SWITCH_REVERSE_IDX = 3;

    void MANLRCHECK();
    void ARSCLR();
}

namespace host {
    void ProcPc();
    void setup();
}

namespace aux {
    void setup();
    void loop();

    uint8_t copyAux();
    void clearInAux(uint8_t toClear);
    void setInAux(uint8_t toSet);
    void toggleInAux(uint8_t toToggle);

    // these outputs on the aux board were physical pins on the 6805
    const uint8_t PRIRADR_M =  0x02u; // High means Radio LEFT is primary now
    const uint8_t RXAUDL_M =  0x40u; // Left headphone relay
    const uint8_t RXAUDR_M =  0x01u; // Right headphone relay
    const uint8_t PTTOUTL_M = 0x04u; // Left PTT
    const uint8_t PTTOUTR_M = 0x08u; // Right PTT
    const uint8_t CWOUTL_M =  0x20u; // Left CW
    const uint8_t CWOUTR_M =  0x10u; // Right CW
    const uint8_t PRIRADL_M = 0x80u; // on other lpt port, but matches PRIRADR_M
    // ... in order to match MK-1100 behavior
}

namespace cw {
    const uint8_t CW_MARK = 0;
    const uint8_t CW_SPACE = 1;
    const uint8_t CW_IDLE = 2;
    const uint8_t CW_WAIT = 3;
    const uint8_t CW_TUNE = 4;
    const uint8_t CW_BUG = 5;
    const uint8_t CW_NUMSTATES = 6;

    // the ALL CAPS variable names to match those in the 6805 assembler.
    volatile uint8_t CWSTATE;
    volatile uint8_t CWPTRIN;
    volatile uint8_t CWPTROU;
    volatile uint8_t CWBUFF[8];
    volatile uint8_t DOTLEN; // morse dot
    volatile uint16_t LTRLEN; // normally twice dot, but farnsworth lengthens
    volatile int8_t WEIGHT; // WEIGHT is SIGNED
    volatile uint8_t PTTIDL;

    /* volatile
     * its necessary to declare variables that are touched by both mainline
     * and interrupt service routines as "volatile". That keeps the optimizer
     * from emitting mainline code that misses changes made by interrupt service
     * routines. But volatile is a really brutal de-optimization. Every single
     * reference in source code to a volatile memory location goes to memory
     * with no use of machine registers.
     *
     * The code below reintroduces the optimization by using variables to hold
     * and modify an otherwise "volatile" memory location, and then store
     * the result back after a series of modifications. This means, of course,
     * that changes by an interrupt service routine over that sequence
     * will be lost. So this coding technique can only be used in routines
     * running with noInterrupts, or as an interrupt service routine.
     */

    void setup();
    void loop();
    unsigned long getCount();
    void SWI(); // was "software interrupt" in 68HC705 code
    // SWI ran out-of-order on the 6805. That is, it didn't
    // actually run until interrupts were next enabled.
    // That difference, though, does not affect the match
    // between MK-1100 and MK-1101 behavior.
    void CLRCWBUF();
    void OutputCw(bool Mark);
}

namespace ptt {
    void loop();
    void SetPttOn();
    void SetPttOff();
    void SETUPPTTDELAY();
    void setup();
    volatile uint16_t PttCntHiLo;
    volatile uint8_t PTTDELAY;
}

namespace diag {
    void CheckSerial();
    void incomingChar(uint8_t);
    bool printCommands = false;
}

// globals carried over from PCKY_P1.ASM
namespace {
    const uint8_t BUFNOTETY = 1 << 0; // CW buffer not empty
    const uint8_t AUDLATCH = 1 << 1;    // Audio latch
    const uint8_t PADDACTI = 1 << 2;    // Paddles active
    // Below appear in host shifted three bits lower in byte (bits 0 through 4)

    // Sidetone bits are negative logic: ON means supress sidetone
    const uint8_t STMACHINE = 1 << 3;   // Sidetone on machine sent
    const uint8_t STONPDLS = 1 << 4;    // Sidetone on paddles
    const uint8_t PRIRADDLOAD = 1 << 5;  // Primary radio. ON is Right
    const uint8_t HDPHSPLIT = 1 << 6;   // Headphones split
    const uint8_t AUTOLTR = 1 << 7;     // Auto letter space

    uint8_t KNOBSPD;    // CW knob speed
    //the bit layout of ARSLATCH match 68hc705 code 
    volatile uint8_t ARSLATCH;
}

//The setup function is called once at startup of the sketch
void setup()
{
    Serial.begin(9600); // Serial I/O is for debugging only
    Serial.println(
#if (MK110X_BUILD == MK1101_BUILD_DEFINITION)
        F("MK1101/MK1102")
#else
        F("MK1103/MK1104")
#endif
    );

    // These pins have nothing to do with Serial library
    // The MK-110x is the Data Set (not Data Terminal)
    pinMode(CTS_PIN, OUTPUT);
    pinMode(DSR_PIN, OUTPUT);
    pinMode(DCD_PIN, OUTPUT);
    pinMode(RTS_PIN, INPUT);
    pinMode(DTR_PIN, INPUT);

    digitalWrite(SPEEDPOT_PIN, LOW);
    pinMode(SPEEDPOT_PIN, INPUT);

    pinMode(CWDOT_PIN, INPUT_PULLUP);
    pinMode(CWDASH_PIN, INPUT_PULLUP);
    pinMode(FOOTTIP_PIN, INPUT_PULLUP);
    pinMode(LRSWITCH_PIN, INPUT_PULLUP);

    digitalWrite(AUX_SELECT_PIN, HIGH);
    pinMode(AUX_SELECT_PIN, OUTPUT);
    digitalWrite(CWL_PIN, LOW);
    pinMode(CWL_PIN, OUTPUT);
    digitalWrite(CWR_PIN, LOW);
    pinMode(CWR_PIN, OUTPUT);
    digitalWrite(PTTL_PIN, LOW);
    pinMode(PTTL_PIN, OUTPUT);
    digitalWrite(PTTR_PIN, LOW);
    pinMode(PTTR_PIN, OUTPUT);
    digitalWrite(CW_SIDETONE_PIN, LOW);
    pinMode(CW_SIDETONE_PIN, OUTPUT);

    digitalWrite(CTS_PIN, LOW);
    digitalWrite(DSR_PIN, LOW);
    digitalWrite(DCD_PIN, HIGH);

    analogReference(DEFAULT);

    SPI.begin();
    cw::setup();
    aux::setup();
    host::setup();
    ptt::setup();
}

// The loop function is called in an endless loop
void loop()
{
     /*
    POLLLOOP:
    RSP
    BSET    OCIE,TCSR       ;ensure 512 usec interrupt
    CLI                     ;Enable interrupts

    CLRA
    STA     COP             ;tell watchdog to go back to sleep
    LDX     CWSPDST
    ASLX
    JSR     CWSPDISP,X      ;dispatch on CW speed state

    SEI
    BSR     PROCPC
    CLI     ;allow interrupt routines to bust in here...

    SEI                       ;check the CW paddles and respond accordingly
    BSR     PDLCHECK
    CLI     ;allow interrupt routines to bust in here...

    SEI
    BSR     PROCPC
    CLI     ;allow interrupt routines to bust in here...

    BSR     MANLRCHECK

    BSR     FTPTTCHECK

    SEI
    JSR     ARSCLR

    BSET    CANDOBUGTUNE,                                                                 ;Identifies this ROM to other side
    BRA     POLLLOOP
*/

/*interrupts and noInterupts
** The 68HC705 code ran the main loop with interrupts OFF, turning them ON inside the loop
** and turning them back off. The arduino code can't quite do the same as it uses SPI and analogRead
** which require interrupts to be turned ON to work.
** 
** In this sketch, the responsibility for cli/sei is inside the routines themselves.
** struct LockInterrupts, below, helps.
*/
    aux::loop();
    host::ProcPc();
    cw::loop();
    MANLRCHECK();
    ptt::loop();
    ARSCLR();
    diag::CheckSerial();
}

// instance one of these to turn off interrupts. The compiler
// will find all the exit paths and turn interrupts back on.
struct LockInterrupts {
    LockInterrupts()
    {  noInterrupts();}
    ~LockInterrupts()
    { interrupts();   }
};

namespace aux {
    volatile uint8_t AuxBoardOutput;
    uint8_t AuxBoardAnt; // not touched by interrupt service

    inline uint8_t copyAux()
    {        return AuxBoardOutput;    }

    inline void clearInAux(uint8_t toClear)
    {        AuxBoardOutput &= ~toClear;    }

    inline void setInAux(uint8_t toSet)
    {        AuxBoardOutput |= toSet;    }

    inline void toggleInAux(uint8_t toToggle)
    {       AuxBoardOutput ^= toToggle;}

     // SPI send of 16 bits to Aux board
    void ToAuxBoard(uint8_t v, uint8_t ant)
    {
        digitalWrite(AUX_SELECT_PIN, LOW);
        SPI.beginTransaction(SPISettings(SPI_MK110x_HZ, MSBFIRST, SPI_MODE3));
        SPI.transfer(v);
        SPI.transfer(ant);
#if (MK110X_BUILD == MK1103_BUILD_DEFINITION)
        // the MK1103 circuit has 3 bytes in the shift register, and the closest
        // one to this MCU has K11/K12 control in same bits as farthest one in MK1102
        SPI.transfer(v);
#endif
        SPI.endTransaction();
        digitalWrite(AUX_SELECT_PIN, HIGH);
    }

    void setup()  {  ToAuxBoard(copyAux(), AuxBoardAnt);    }

    void loop()
    {
        static uint8_t lastUpdated;
        static uint8_t lastAnt;
        uint8_t aux = copyAux();
        if ((aux != lastUpdated) || (AuxBoardAnt != lastAnt))
        {
            lastUpdated = aux;
            lastAnt = AuxBoardAnt;
            ToAuxBoard(aux, AuxBoardAnt);
        }
    }
}
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
    void loop()
    {
        /*
FTPTTCHECK:      ;CHECK FOOT PTT SWITCH INPUT
    BRSET FTPTTIN,PORTC,FTPTTISOFF
    ;foot switch PTT is ON
    JSR SETPTTON
    LDA #FTPTTONCNT
    STA FTPTTONST
    RTS
FTPTTISOFF:
    TST FTPTTONST
    BEQ FTPTTDONE
    DEC FTPTTONST
    BNE FTPTTDONE
    JSR SETPTTOFF
FTPTTDONE:
    RTS
         */
        LockInterrupts l;
        if (digitalRead(FOOTTIP_PIN) == LOW)
        {
            SetPttOn();
            FTPTTONST = FTPTTONCNT;
        }
        else if (FTPTTONST != 0)
        {
            if (--FTPTTONST == 0)
                SetPttOff();
        }
    }

    void SetPttOn()
    {
        bool isLeft = (aux::copyAux() & aux::PRIRADL_M) != 0;
        uint8_t toSet = isLeft ?
            aux::PTTOUTL_M : aux::PTTOUTR_M;
        aux::setInAux(toSet);
        digitalWrite(isLeft ? PTTL_PIN : PTTR_PIN, HIGH);
    }

    void SetPttOff()
    {
        aux::clearInAux(aux::PTTOUTL_M | aux::PTTOUTR_M);
        digitalWrite(PTTL_PIN, LOW);
        digitalWrite(PTTR_PIN, LOW);
    }

    void SETUPPTTDELAY()
    {   // call with ********** noInterrupts *****************
        /*
SETUPPTTDELAY:
    ; if we have a PTT delay, and PTT is OFF, then that's how long we must wait
        LDA  PTTDELAY
        BEQ  PTTDELDONE; Don't have any
        LDA PORTC; LOAD BOTH PTT outputs  at once...
        AND #{PTTOUTL_M | PTTOUTR_M}
    BNE  PTTDELDONE; already on
        JSR  SETPTTON
        LDA  PTTDELAY
        STA  NEXTLOW
        CLR  NEXTHI
    PTTDELDONE :
    RTS
    */
        if (PTTDELAY)
        {
            if (0 != (aux::copyAux() & (aux::PTTOUTL_M | aux::PTTOUTR_M)))
                return;
            SetPttOn();
            cw::NEXTHILO = PTTDELAY;
        }
    }
}

namespace diag {
  /* The Arduino serial port in normal MK-1101 operation is wired to nothing,
   *  and unused. The code in this namespace monitors that serial port
   *  (9600 bauds) and, should it be connected, executes certain commands.
   */
    const int HOST_BUFFER_LENGTH = 80;
    char fromHostbuffer[HOST_BUFFER_LENGTH + 1]; // +1 so we can add trailing null
    int charsInBuf = 0;
    bool pauseBetweenTests;
    void SelfTest();
    void SOUNDTEST();
    void SPEEDTEST();

    void pause()
    {
        if (!pauseBetweenTests)
            return;
        Serial.println(F(" ...any key to continue"));
        while (!Serial.available());
        Serial.read();
        return;
    }

    uint8_t asciiToBin(const char *p)
    {
        uint8_t s = 0;
        while (isdigit(*p))
        {
            s *= 10;
            s += *p++ - '0';
        }
        return s;
    }

    void ProcessHostCommand()
    {
        bool echo = true;
        static const char printOn[]  = "printOn";
        static const char printOff[]  = "printOff";
        static const char printCount[] = "printCount";
        static const char potLR[] = "potLR";
        static const char sound[] = "sound";
        static const char knobSpd[]  = "knobSpd=";
        static const unsigned knobSpdLen = -1 + sizeof(knobSpd) / sizeof(knobSpd[0]);
        static const char DCDup[]  = "DCDup";
        static const char DCDdown[]  = "DCDdown";
        static const char selfTest[]  = "selfTest";
        static const char knobOn[] = "knobOn";
        static const char knobOff[] = "knobOff";
        static const char hostDump[] = "hostDump";
        static const char knob[] = "readKnob";
        static const char knobRev[] = "knobRev";
        static const char knobFwd[] = "knowFwd";
        static const char lrNormal[] = "LRnormal";
        static const char lrRev[] = "LRrev";
        static const char pttDel[] = "pttDel=";
        static const char paddles[] = "paddles";
        static const char pauseOn[] = "pauseOn";
        static const char pauseOff[] = "pauseOff";
        static const unsigned pttDelLen = -1 + sizeof(pttDel);
        if (strcmp(fromHostbuffer, printOn) == 0)
            printCommands = true;
        else if (strcmp(fromHostbuffer, printOff) == 0)
            printCommands = false;
        else if (strcmp(fromHostbuffer, printCount) == 0)
        {
            Serial.print(F("512 usec counter: "));
            Serial.println(cw::getCount());
            echo = false;
        }
        else if (strncmp(fromHostbuffer, knobSpd, knobSpdLen) == 0)
        {   // simulate turning the pot
            uint8_t s = asciiToBin(fromHostbuffer + knobSpdLen);
            KNOBSPD = s;
            cw::DOTLEN = s;
            cw::LTRLEN = s << 1;
        }
        else if (strncmp(fromHostbuffer, pttDel, pttDelLen) == 0)
        {
            uint8_t s = asciiToBin(fromHostbuffer + pttDelLen);
            EEPROM.write(PTT_DELAY_IDX, s);
            ptt::PTTDELAY = s;
        }
        else if (strcmp(fromHostbuffer, DCDup) == 0)
            digitalWrite(DCD_PIN, HIGH);
        else if (strcmp(fromHostbuffer, DCDdown) == 0)
            digitalWrite(DCD_PIN, LOW);
        else if (strcmp(fromHostbuffer, selfTest) == 0)
            SelfTest();
        else if (strcmp(fromHostbuffer, knobOn) == 0)
            EEPROM.write(KNOB_EPROM_IDX, 1);
        else if (strcmp(fromHostbuffer, knobOff) == 0)
            EEPROM.write(KNOB_EPROM_IDX, 0);
        else if (strcmp(fromHostbuffer, knobRev) == 0)
            EEPROM.write(KNOB_REVERSE_IDX, 0);
        else if (strcmp(fromHostbuffer, knobFwd) == 0)
            EEPROM.write(KNOB_REVERSE_IDX, 1);
        else if (strcmp(fromHostbuffer, lrNormal) == 0)
            EEPROM.write(LR_SWITCH_REVERSE_IDX, 1);
        else if (strcmp(fromHostbuffer, lrRev) == 0)
            EEPROM.write(LR_SWITCH_REVERSE_IDX, 0);
        else if (strcmp(fromHostbuffer, hostDump) == 0)
        {
            echo = false;
            Serial.print("EEPROM: KnobEnabled=");
            Serial.print((int)EEPROM.read(KNOB_EPROM_IDX));
            Serial.print(" PTT delay="); Serial.print((int)EEPROM.read(PTT_DELAY_IDX));
            Serial.print(" knobRev="); Serial.print((int)EEPROM.read(KNOB_REVERSE_IDX));
            Serial.print(" LRreverse="); Serial.print((int)EEPROM.read(LR_SWITCH_REVERSE_IDX));
            Serial.print(" DOTLEN="); Serial.print(cw::DOTLEN);
            Serial.print(" LTRLEN="); Serial.println(cw::LTRLEN);
        }
        else if (strcmp(fromHostbuffer, knob) == 0)
        {
            analogReference(DEFAULT);
            int spd = analogRead(SPEEDPOT_PIN);
            Serial.print("Pot="); Serial.println(spd);
            echo = false;
        }
        else if (strcmp(fromHostbuffer, potLR) == 0)
        {
            SPEEDTEST();
        }
        else if (strcmp(fromHostbuffer, sound) == 0)
        {
            SOUNDTEST();
        }
        else if (strcmp(fromHostbuffer, paddles) == 0)
        {
            Serial.print("Dot=");
            Serial.print(digitalRead(CWDOT_PIN) == LOW ? "on" : "off");
            Serial.print(" Dash=");
            Serial.println(digitalRead(CWDASH_PIN) == LOW ? "on" : "off");
        }
        else if (strcmp(fromHostbuffer, pauseOn) == 0)
            pauseBetweenTests = true;
        else if (strcmp(fromHostbuffer, pauseOff) == 0)
            pauseBetweenTests = false;
        else
            echo = false; // unknown commands do NOT echo
        // ...so TXD/RXD can be looped back when diag port disconnected.
        if (echo)
            Serial.println(fromHostbuffer);
    }

    void incomingChar(uint8_t c)
    {
        if (printCommands)
        {
            Serial.print(F("incoming Char: 0x"));
            Serial.println(c, HEX);
        }
    }

    void CheckSerial()
    {
        while (Serial.available() > 0)
        {
            char input = Serial.read();
            static bool overflow = false;
            bool inputIsNewline = (input == '\r') || (input == '\n');
            if (!inputIsNewline) // not a carriage return
            {
                if (charsInBuf >= HOST_BUFFER_LENGTH)
                {
                    overflow = true;
                    charsInBuf = 0;
                }
                if (!overflow)
                {
                    fromHostbuffer[charsInBuf] = input;
                    charsInBuf++;
                }
            }

            if (inputIsNewline)
            {
                if (charsInBuf > 0)
                {
                    fromHostbuffer[charsInBuf] = 0;
                    ProcessHostCommand();
                }
                overflow = false;
                charsInBuf = 0;
            }
        }
    }

    uint8_t const P12Lights[3]  = { aux::PRIRADR_M, aux::CWOUTR_M, aux::PTTOUTR_M };
    uint8_t const P13Lights[3]  = { aux::PRIRADL_M, aux::CWOUTL_M, aux::PTTOUTL_M };
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

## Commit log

2018-02-12 more schematics
2018-02-28 firmware and layouts
    [MK1102-schematic.sch]
2018-02-28 drilling template and silkscreen
2021-12-29 PCB layout and diagram
    [MK1103-schematic.sch]
2021-12-30 pad connections to ground
2021-12-31 move front panel items
    [MK1103-schematic.sch]
2021-12-31 move CAD front panel
2021-12-31 enclosure back overlap pcbs
2021-12-31 relay edge clearance pcb
2021-12-31 relay clearance
2022-01-01 vias etc
    [MK1103-schematic.sch]
2022-01-02 cuttable board for MK-1103 vs MK-1104
    [MK1103-schematic.sch]
2022-01-05 rearrange directories for MK1101 vs MK1103
    [MK1102-schematic.sch, MK1104-schematic.sch]
2022-01-07 pcb clean up
2022-01-08 aux board name
2022-01-17 solid edge
    [Adafruit FT232H.cfg, D9-Sub Connector.cfg, LR switch.stp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]
2022-01-23 REV02 of main board
    [MK1104-schematic.sch]
2022-01-23 after first build mk1103/mk1104
    [621-009-260-042 - EDAC D-Sub Connector.STEP, MK1103-Enclosure.cfg, pcb-main-mk1103-solder-paste.stl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]
2022-02-03 update enclosure
    [MK1103-Enclosure.cfg]
2022-02-04 mk1104 enclosure
    [MK1104-Enclosure.cfg, PcbAuxAssembly.cfg, PcbMainMK1104.cfg]
2022-02-05 power up reset shift register
    [MK1104-schematic.sch]
2022-02-05 switch diag/rig
    [MK1104-schematic.sch]
2022-02-06 hole for reset
2022-02-06 diag switch
    [MK1104-Enclosure.cfg, PcbAuxAssembly.cfg, PcbMainMK1104.cfg]
2022-02-06 smaller hole
2022-02-07 use software switch for diagnostics
    [MK1104-schematic.sch]
2022-02-07 one less hole
    [MK1104-Enclosure.cfg, PcbMainMK1104.cfg]
2022-02-07 part numbering corrections
    [MK1104-schematic.sch]
2022-02-08 tri 3-input nand
    [MK1104-schematic.sch]
2022-02-08 clear ribbon cable connectors
2022-02-08 clear ribbon cables
    [MK1104-Enclosure.cfg, PcbAuxAssembly.cfg, PcbMainMK1104.cfg]
2022-02-08 move connectors
    [MK1104-Enclosure.cfg, PcbAuxAssembly.cfg, PcbMainMK1104.cfg]
2022-02-09 jp1 jp2
    [MK1104-schematic.sch]
2022-02-25 schematic cosmetics
    [MK1104-schematic.sch]
2022-02-26 594 not 595
    [MK1104-schematic.sch]
2022-02-26 schematic matches pcb
2022-02-27 more startup C
    [MK1104-schematic.sch]
2022-02-27 more model
    [MK1103-Enclosure.cfg, MK1104-Enclosure.cfg, PcbMainMK1104.cfg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]
2022-03-03 better knob
    [MK1103-Enclosure.cfg]
2022-03-03 hole in mk1103 case
    [MK1103-Enclosure.cfg]
2022-03-06 front panel
    [MK1104-Enclosure.cfg]
2022-03-07 pcb updates
    [MK1104-schematic.sch]
